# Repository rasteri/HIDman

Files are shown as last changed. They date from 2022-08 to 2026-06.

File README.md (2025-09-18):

# HIDman
## USB HID to XT / AT / PS/2 / Serial converter

HIDman is an open source device to allow the use of modern USB keyboards and mice on legacy PCs.

Peripherals that support legacy PCs are becoming hard to find, especially for the very first PCs. This project aims to provide a simple cheap solution that will cover everything from the original IBM 5150 PC all the way up to modern computers that have PS/2 ports.

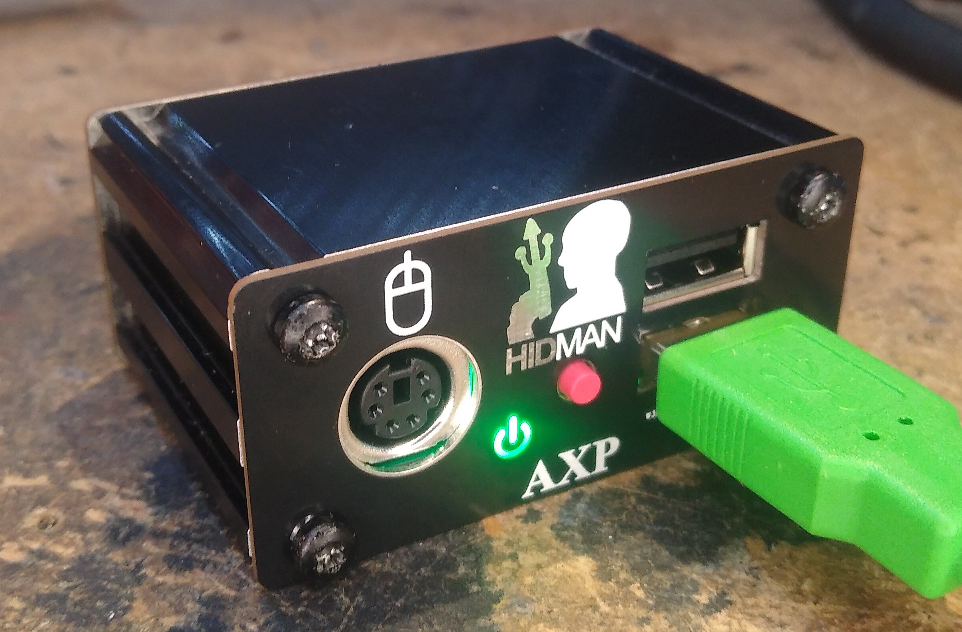
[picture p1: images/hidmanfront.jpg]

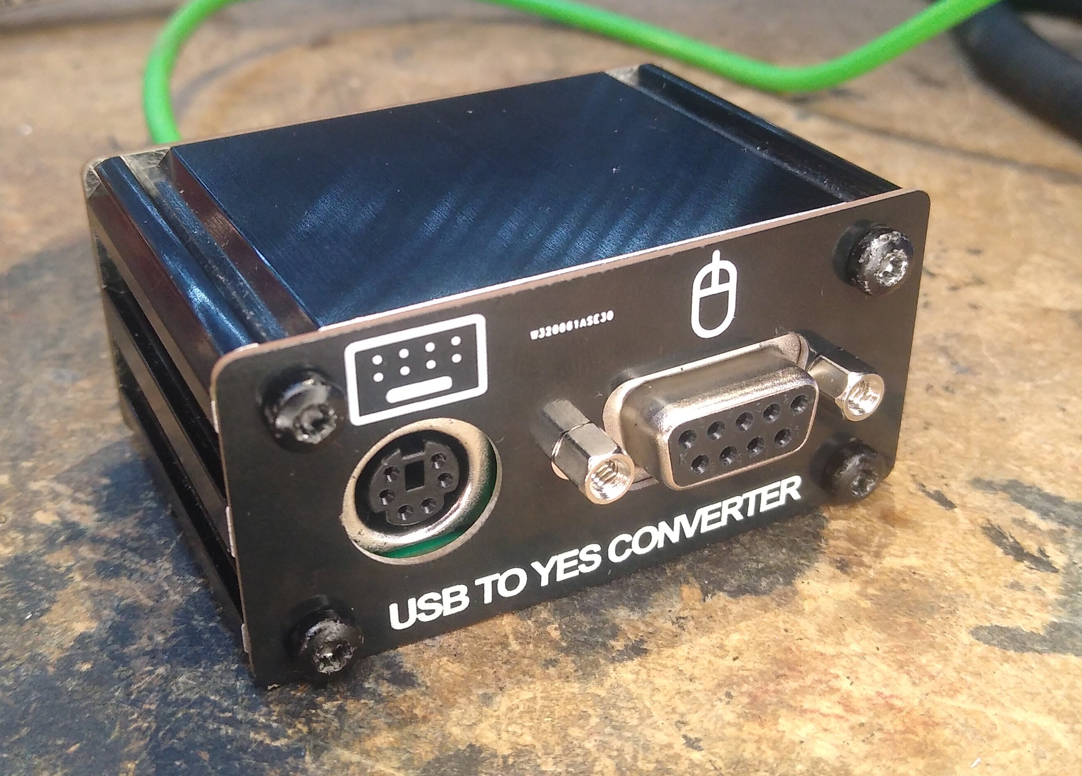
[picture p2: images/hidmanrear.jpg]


# Features

* (should) Support the majority of standard USB keyboards and mice, including ones that use wireless dongles.
* Also supports (some) USB Game controllers - buttons/axes are mapped to keypresses or mouse actions
* Can emulate the following keyboards :
  * Original IBM PC, XT and clones
  * AT / PS/2
  * Amstrad PC (PC1512, PC1640, PC2xxx, PC3xxx, PC4xxx)
* And the following mice :
  * Serial Mouse (with optional Logitech-style 3rd button)
  * PS/2 Mouse (with optional Intellipoint-style scroll wheel and up to 5 buttons)
* Driverless configuration menu - change settings just by opening a text editor

# How to get one

## Purchase : 

* I have some for sale on my tindie page - https://www.tindie.com/products/rasteri/hidman/
* If you're in the US, retro hack shack also has stock - https://retrohackshack.com/product/hidman-usb-keyboard-converter/

## DIY : 

* Grab an assembled PCB from PCBway : https://www.pcbway.com/project/shareproject/HIDman_USB_to_Retro_PC_Adapter_3b4fb5d5.html
* Also grab the front plate : https://www.pcbway.com/project/shareproject/Front_enclosure_plate_for_HIDman_0aec2ae9.html
* And the rear plate : https://www.pcbway.com/project/shareproject/Rear_Enclosure_for_HIDman_c0ff0b8a.html
* And the enclosure : https://lincolnbinns.com/e-case-a-black-40mm.html
* Don't forget 8x screws : https://lincolnbinns.com/e-case-screws.html (I suggest the thread former ones)
* After assembling the unit, you will need to install firmware. See the "Firmware Update" section below.

# Quickstart Guide

## USB Connection

You can connect many different combinations of USB devices to HIDman.

The most obvious being to connect a keyboard to one USB port, and a mouse to the other one :



Or, you could perhaps connect a wireless keyboard+mouse dongle to one port, and a game controller to the other :



Hub support can be hit-and-miss. This is (mostly) not HIDman's fault - many modern hubs don't support low-speed USB devices properly.

## Newer PCs (PS/2) ###

* Connect male-to-male Mini-DIN cables from HIDman’s keyboard and mouse ports to your PC’s PS/2 ports.
* Turn on your PC.
* If necessary, press HIDman's ⏻ power button to select PS/2 mode (light blue).



## Older PCs (AT/XT and Serial)

* Connect a male-to-male Mini-DIN Cable from HIDman's keyboard port into a Mini-DIN to DIN adapter.
* Connect that adapter to your PC's keyboard port.
* Connect a straight-through male-to-female DE-9 cable from HIDman's serial port to your PC's serial port.
* Turn on your PC.
* Press HIDman's ⏻ power button to select AT mode (light blue), or XT mode (orange) for early 80's IBM PCs and clones.



# Configuration

Configuration is provided through a built-in menu system. No software install is required - all interaction is through the keyboard.

Simply open a text editor on your target PC (eg notepad, edit, vi), then hold HIDman's power button for a few seconds. The menu will be typed out into your text editor.

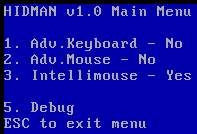
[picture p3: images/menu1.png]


"Adv.Keyboard" and "Adv.Mouse" switch the keyboard and mouse respectively into "Native Mode". This may be required to access certain functions such as scroll wheels and extra buttons on mice.

**Note : Some USB devices with both keyboard and mouse interfaces (e.g. mice with configurable buttons) require both Adv.Keyboard and Adv.Mouse to be enabled otherwise they behave unpredictably.**

"Intellimouse" enables scroll wheel and 5-button support for PS/2 mice.

"Debug" enables the debug menu. The most useful debugging option is "Dump HID Data". Enabling this dumps information about all USB devices connected after that point. 



If you are having trouble getting a USB device to work, enable HID Dumping then connect the troublesome USB device. Wait for it to finish dumping, then press ESC and save the resulting data to a text file. Then send it to me for analysis.

# Firmware Update

Firmware development is continuing, so if you have problems it's always worth updating to the latest version.

If you're on windows, first install WCH's ISP tool - https://www.wch.cn/downloads/WCHISPTool_Setup_exe.html
If on Mac or Linux, install ch55xtool : https://github.com/MarsTechHAN/ch552tool

The next step is to put the HIDman in firmware update mode.

1. Disconnect everything from HIDman, including all USB devices and PCs. (failure to do this may result in damage to HIDman, your PC, or both).
2. Hold down HIDman's ⏻ power button.
3. Use a USB A-to-A cable to connect HIDman's LOWER USB port to a USB port on your modern PC.

If HIDman doesn't appear in your computers' device list, follow the instructions in the "Debricking" section below.

After that, update instructions will depend on your operating system.

## Windows

Follow the instructions in this diagram :



## Linux or Mac

Pass the -f parameter to ch55xtool specify the firmware file to load. For example :

```
python3 ch55xtool.py -f hidman_axp_v1.1.bin
```

## Debricking

If this is your first time programming HIDman, or you accidentally program a corrupted firmware, you can force it into firmware update mode another way. It can be a bit fiddly though.

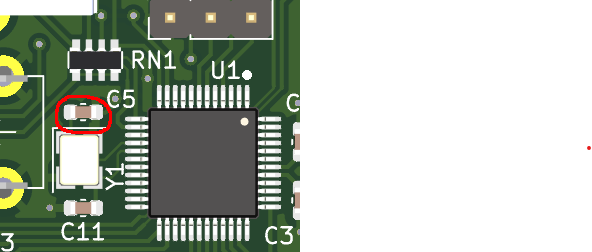
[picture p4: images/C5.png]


1. Disassemble HIDman.
2. Connect the two pads of component C5 (shown above) together using a pair of tweezers or similar.
3. While keeping the pads connected, use a USB A-to-A cable to connect HIDman's LOWER USB port to a USB port on your modern PC.

# Advanced Setups

## Combined PS/2 port
HIDman actually outputs keyboard *and* mouse signals on **BOTH** PS/2 connectors. If you have a PC that can take advantage of this (typically Mini PCs or Laptops), you can keep the cabling neater by using only one cable. **NOTE : You will need to enable "PS2 AUX Output" in the advanced menu.**



Note that there are two different types of Combined PS/2 ports, and HIDman provides for both types. Generally, laptops will need plugged into the Mouse port on HIDman, and Mini PCs want the Keyboard port. If it doesn't work with one port, try the other one.

## Splitter

Another way to take advantage of the Combined PS/2 port functionality is to use a widely-available PS/2 splitter :



This also allows neater cabling, as you could connect both keyboard and mouse ports to the rear, and not have to connect to the front mouse port.

## Technical description

The HIDman is based around the CH559 from WCH, a remarkably flexible chip with **two** USB HOST ports. This makes it ideal for our purposes.

The code is forked from atc1441's excellent repository - https://github.com/atc1441/CH559sdccUSBHost

PCB and enclosure was designed in KiCad - source files are in the hardware directory.

Development is very active but it is usable in its current state.

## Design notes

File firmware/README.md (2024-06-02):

# HIDman
## USB HID to XT / AT / PS/2 / Serial converter

HIDman is an open source device to allow the use of modern USB keyboards and mice on legacy PCs.

Peripherals that support legacy PCs are becoming hard to find, especially for the very first PCs. This project aims to provide a simple cheap solution that will cover everything from the original IBM 5150 PC all the way up to modern computers that have PS/2 ports.

Hidman Front
Hidman Front

## Features

* (should) Support the majority of standard USB keyboards and mice, including ones that use wireless dongles.
* Also supports (some) USB Game controllers - buttons/axes are mapped to keypresses or mouse actions
* Can emulate the following devices :
* * OG IBM PC / XT Keyboard
  * AT / PS/2 Keyboard
  * Serial Mouse (with optional Logitech-style 3rd button)
  * PS/2 Mouse (with optional Intellipoint-style scroll wheel and up to 5 buttons)
* Driverless configuration menu - change settings just by opening a text editor

## Technical description

The HIDman is based around the CH559 from WCH, a remarkably flexible chip with **two** USB HOST ports. This makes it ideal for our purposes.

The code is forked from atc1441's excellent repository - https://github.com/atc1441/CH559sdccUSBHost

PCB and enclosure was designed in KiCad - source files are in the hardware directory.

Development is very active but it is usable in its current state.

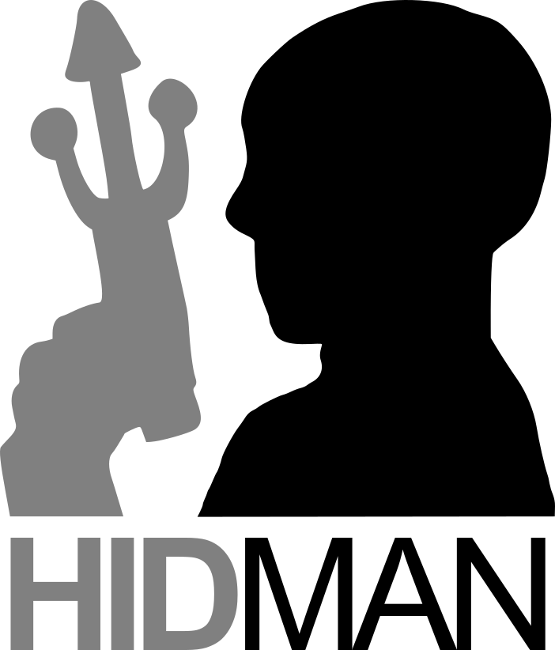
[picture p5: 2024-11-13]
hardware/assets/path676.png

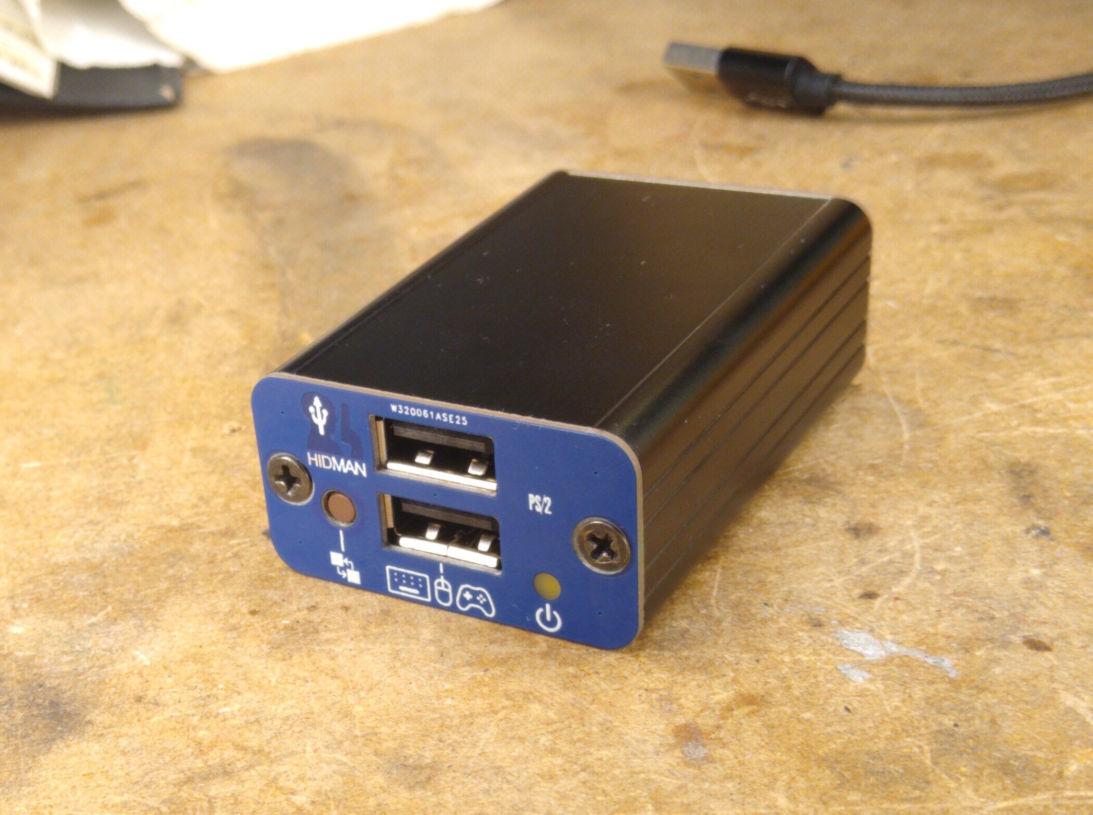
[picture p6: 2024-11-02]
hardware/ps2/images/HIDman-ps2-front.jpg

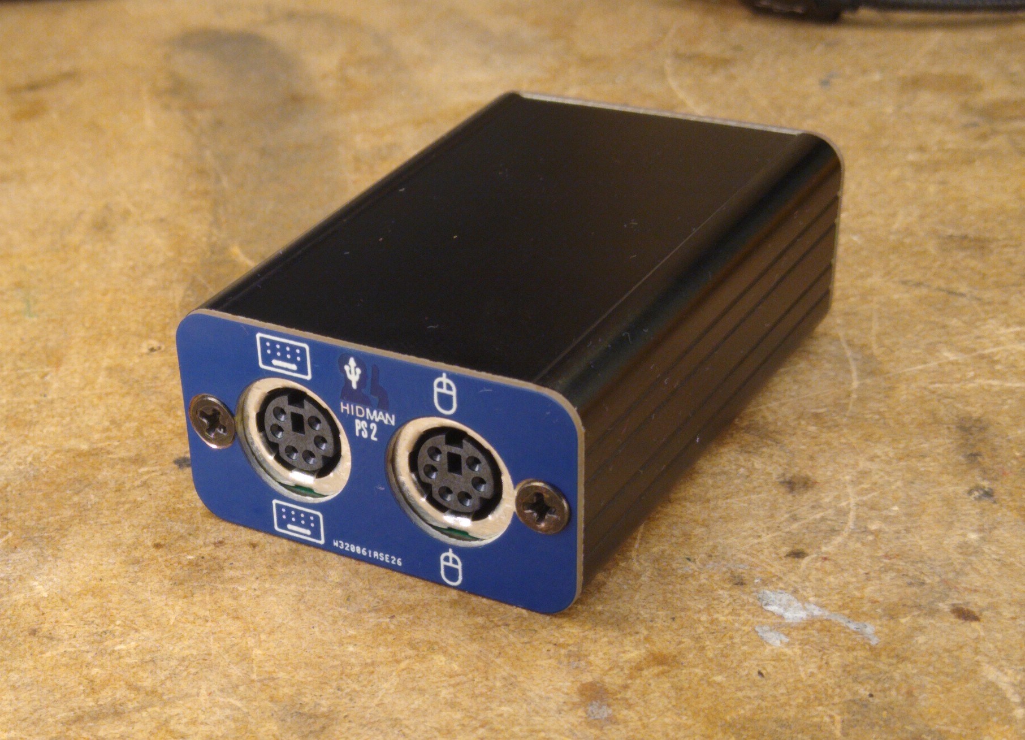
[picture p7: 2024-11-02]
hardware/ps2/images/HIDman-ps2-rear.jpg

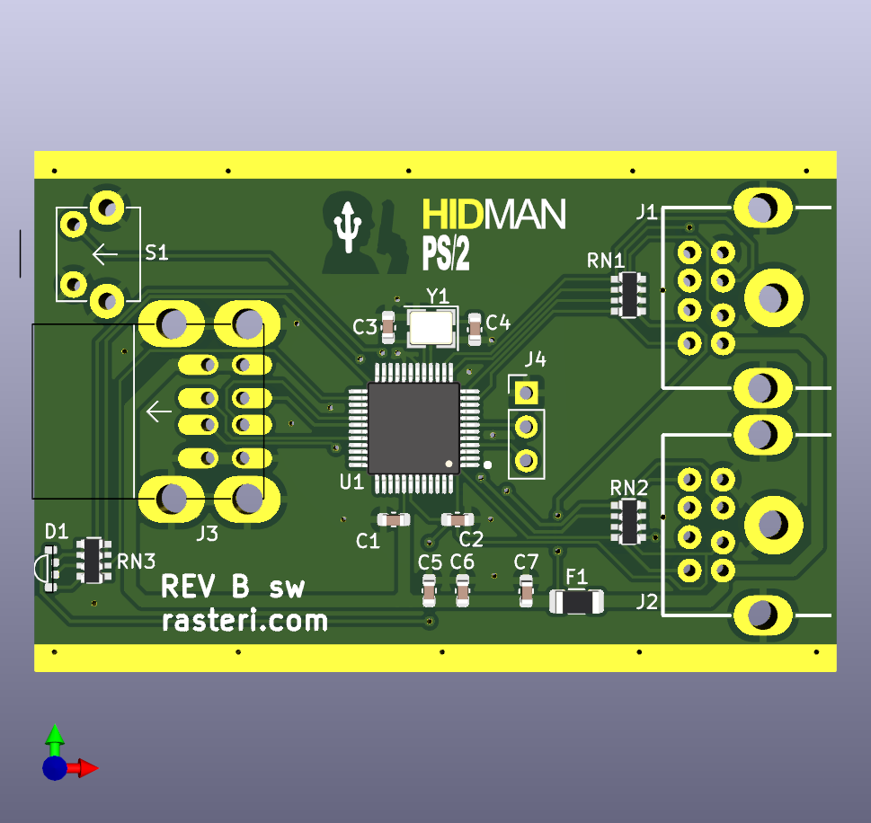
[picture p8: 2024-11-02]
hardware/ps2/ps2usb.png

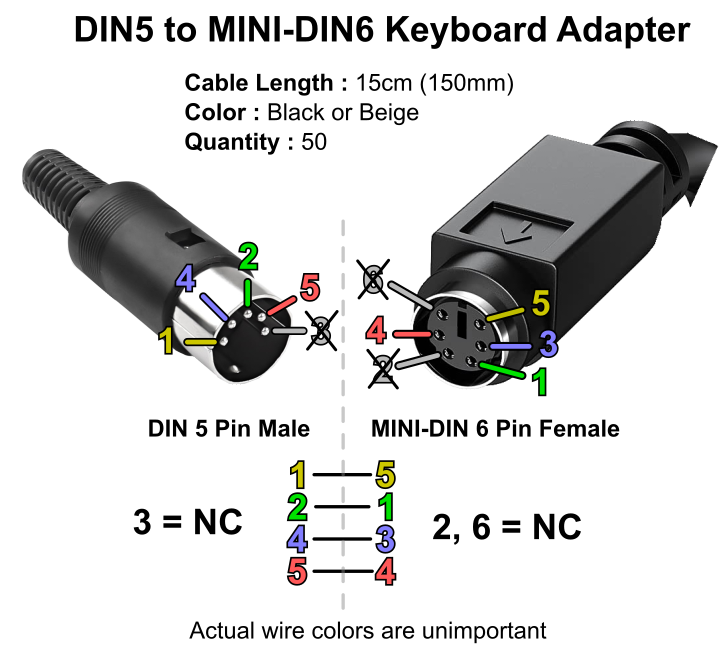
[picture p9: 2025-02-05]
images/adapt.png

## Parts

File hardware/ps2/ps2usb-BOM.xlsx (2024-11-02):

Designator | Manufacturer | Part Number | Description | Footprint | JLCPCB Part #
C1,C2,C5,C6,C7 | Samsung | CL10A335KP8NNNC | Cap, 0603, MLCC, 3.3uF, 10v, X5R | SMD 0603 | C342962
C3,C4 | YAGEO | CC0603JRNPO9BN100 | Cap, 0603, MLCC, 10pF, 50v, C0G | SMD 0603 | C1634
D1 | Harvatek | B3173BGR-20C0001Q3U1930 | LED, RGB, Common Anode | SMD | C2827295
RN1,RN2 | YAGEO | YC164-FR-071KL | Res Array, 4x0603, 1K | SMD 4x0603 | C110021
RN3 | YAGEO | YC164-JR-07120RL | Res Array, 4x0603, 120R | SMD 4x0603 | C136835
J1,J2 | HOOYA | DIN-603 | Conn, Mini-DIN, 6pin | Through-Hole | C7428703
J3 | SHOU HAN | AF SS-JB17.6 | Conn, USB, 2.0, Type-A, Dual | Through-Hole | C456021
J4 | DO NOT POPULATE | DO NOT POPULATE | DO NOT POPULATE | DO NOT POPULATE
U1 | WCH | CH559L | IC, CH559L | SMD QFP48 | C150548
S1 | CUI | TS11-674-80-BK-160-RA-D | Switch, Tactile, Right Angle, 8mm Actuator Length | Through-Hole | C7074168
F1 | BHFUSE | BSMD1206-050-30V | 500mA | SMD 1206 | C883126
Y1 | YXC | X322512MSB4SI | 12MHz | SMD 3225 | C9002

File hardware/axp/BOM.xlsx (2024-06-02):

Item # | Designators | Quantity | Manufacturer | Part no | Desc | Package | Type
1 | C4,C7,C1,C6,C10,C9,C2,C3,C8,C12 | 10 | Samsung | CL10A335KP8NNNC | Cap, 0603, MLCC, 3.3uF, 10v, X5R | SMD 0603 | SMD
2 | C11,C5 | 2 | YAGEO | CC0603JRNPO9BN100 | Cap, 0603, MLCC, 10pF, 50v, C0G | SMD 0603 | SMD
3 | J3,J1 | 2 | HOOYA | DIN-603 | Conn, Mini-DIN, 6pin | Through-Hole | TH
4 | D1 | 1 | TUOZHAN | P4-1204RGBWS2-1.5T-A | LED, RGB, Common Anode | SMD | SMD
5 | RN3 | 1 | YAGEO | YC164-JR-07120RL | Res Array, 4x0603, 120R | SMD 4x0603 | SMD
6 | RN1,RN2 | 2 | YAGEO | YC164-FR-071KL | Res Array, 4x0603, 1K | SMD 4x0603 | SMD
7 | J2 | 1 | SHOU HAN | AF SS-JB17.6 | Conn, USB, 2.0, Type-A, Dual | Through-Hole | TH
8 | U1 | 1 | WCH | CH559L | IC, CH559L | SMD QFP48 | SMD
9 | U2 | 1 | Texas Instruments | MAX232IDR | IC, MAX232 | SMD SOIC16 | SMD
10 | S1 | 1 | Shenzhen Kinghelm Elec | KH-6X6X9H-ZJ | Switch, Tactile, Right Angle, 9mm Actuator Length | Through-Hole | TH
11 | J5 | 1 | DO NOT POPULATE | DO NOT POPULATE | DO NOT POPULATE | DO NOT POPULATE | -
12 | J4 | 1 | XUNPU | D-SUB-DR-9PCM-CB | Conn, D-Sub, DE-9, 9-pin | Through-Hole | TH
13 | F1 | 1 | BHFUSE | BSMD1206-050-30V | 500mA | SMD 1206 | SMD
14 | Y1 | 1 | YXC | X322512MSB4SI | 12MHz | SMD 3225 | SMD

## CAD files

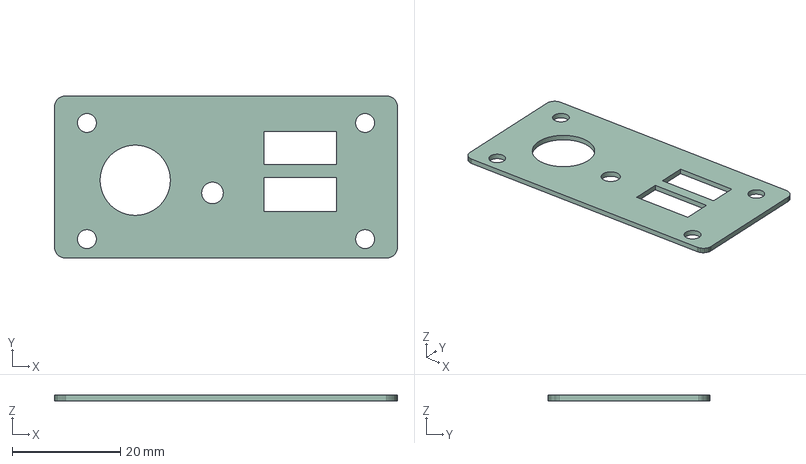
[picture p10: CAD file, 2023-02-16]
hardware/axp/enclosure/frontcase/frontcase.step
63.5 x 30.0 x 1.07 mm

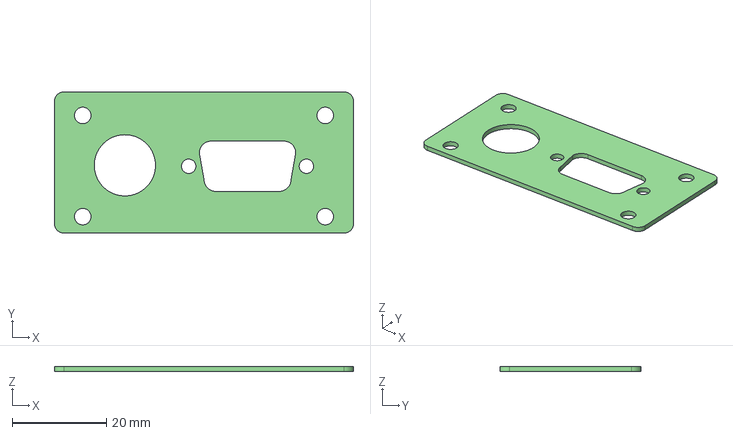
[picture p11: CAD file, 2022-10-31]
hardware/axp/enclosure/rearcase/rearcase/rearcase.step
63.5 x 30.0 x 1.09 mm

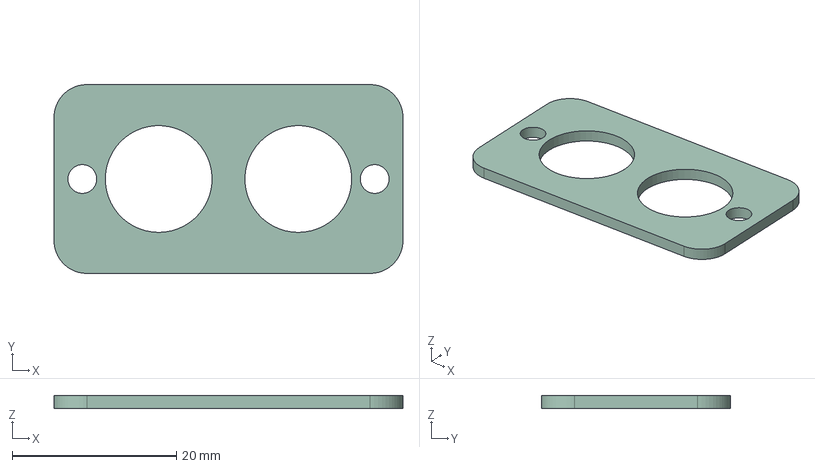
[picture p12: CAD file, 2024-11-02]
hardware/ps2/enclosure/frontcase/frontcase.step
42.5 x 23.0 x 1.60 mm

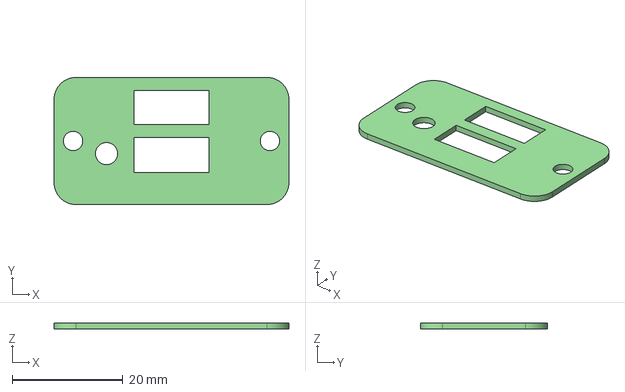
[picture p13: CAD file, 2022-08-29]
hardware/ps2/enclosure/rearcase/rearcase.step
42.5 x 23.0 x 1.09 mm

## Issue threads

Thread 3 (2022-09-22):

Intellimouse features not implemented

rasteri, 2022-09-22:

jarpatus, 2024-05-04:
@rasteri, I am trying to add Intellimouse support and am almost there, but have treoubles on last steps... I wonder if you are willing to help?

I have implemented PS/2 command buffer so I can detect when driver enables intellimouse (also enabled support for PS/2 resolution and scaling on commands, but those are not that important). I have expanded PS/2 related code to support Z-axis and 4-byte reports. At the moment middle click works under DOS and Win98 and wheel scrolling does work if I fake it (e.g. map mouse Y-axis to wheel like I've done for debugging purposes).

However, I am unable to wrap my head around USB code, reports and stuff. I cannot figure out how I can make USB code to support scrolling. If you are willing to help, could you take a look of this commit on my fork:

https://github.com/rasteri/HIDman/commit/f6b9754f5e3a20176eb96b2270da4323d281251c

In ps2protocol.c I think I was able to do what it takes (case MAP_MOUSE_WHEEL), but in parsedescriptor.c my modifications do nothing (case REPORT_USAGE_WHEEL, do not mind swapped Y and wheel, for debugging only). Any hints?

jarpatus, 2024-05-05:
Hacked together wheel support, it works with ctmouse and under Windows98! But it's a hack as I am parsing wheel input from bare data...

rasteri, 2024-05-06:
Hey I'll look at getting it integrated with the HID report stuff. It's a pretty complicated scheme.

jarpatus, 2024-05-06:
@rasteri, I was able to make it work by adding wheel to standard mouse descriptor... not sure if you can do it like this, I still do not understand HID report descriptors and reports well enough...

https://github.com/rasteri/HIDman/commit/96a871553ec7181b16096e851a17616f6e65b321

jarpatus, 2024-05-06:
Thanks! FYI; I felt andventurous and added support for 5 button intellimouse, this is in it's separate branch intelli5b in my fork. Feel free to try it out if you wish. I had to modify standard mouse descriptor even more.

At least under Win9x IntelliPoint 3.0 software will now detect mouse as Intellimouse Explorer with 5 buttons and buttons really do work. I have no modern machines with PS/2 so I could try it out e.g. with Win11 or so...

rasteri, 2024-05-07:
5-button code works flawlessly in Windows 10. I think we can call this one fixed.

Thanks again for your contribution!

Closed 2024-05-07.

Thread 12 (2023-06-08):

Possible to output combined keyboard and mouse?  (re: weeCee PS/2 input)

sofakng, 2023-06-08:
Thanks for the excellent project!

Would you consider adding a feature (to both the 'legacy' PS2 and newer AXP versions) to output both keyboard and mouse on a single PS/2 cable?  For example, your weeCee only has a single PS/2 input and requires both signals on the same cable.

Thanks!

rasteri, 2023-06-08:
I already plan to add this feature - the ports are already wired up for this.

sofakng, 2023-06-08:
Great, thanks so much!  I posted a couple of other questions on Vogons if you have a minute to check.  Thanks again!

rasteri, 2024-05-06:
This is now implemented

Closed 2024-05-06.

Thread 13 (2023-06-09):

What enclosure are you using for the original PS/2 version?

sofakng, 2023-06-09:
What enclosure are you using for the original PS/2 version?

It looks like a Hammond case similar to your weeCee case but I'm not sure.

Thanks for the help!

EDIT:  I think it might be the [Hammond 1455D602BK](https://www.hammfg.com/part/1455D602BK?referer=1203)?

rasteri, 2023-06-09:
It's the 1455D601BK, but the 602 will also work just get whatevers cheaper.

Sorry I'm ignoring vogons, I'm preparing the release of another open source project, Once its done I'll get back to preparing the Hidman 1.0 release

sofakng, 2023-06-09:
No problem and thanks for the reply.  Sorry about the repeated questions.  I was just hoping to order some parts because it takes a few weeks to arrive.

It looks like the only difference between the 601 and 602 are the metal endcaps on the 601 which you aren't using anyways.

Thanks again and I can't wait to see your next project!

Closed 2024-05-07.

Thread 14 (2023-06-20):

Restore PS/2 version functionality

sofakng, 2023-06-20:
Sorry to bother you again...  Can you confirm this is the correct orientation for the LED?  (green dot towards PCB)

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

rasteri, 2023-06-21:
yeah I think that's right.
unfortunately the PS/2 version will need some firmware tweaks to work again - the current code only works for AXP...

I should have some time to work on integrating them soon

sofakng, 2023-06-21:
Ahhh, OK.  That probable explains why I was able to flash the chip but it doesn't seem to work.  I'll keep an eye on any updates.  Thanks!

yarodin, 2023-06-24:
Same story here. Waiting fixed firmware for PS/2 version.

rasteri, 2024-05-07:
This has been fixed - latest firmware supports PS/2 version again.

Closed 2024-05-07.

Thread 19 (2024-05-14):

Some USB Hubs don't work

rasteri, 2024-05-14:
This does not affect all hubs. In fact it doesn't affect all USB devices on failing hubs.

Common thread with failing hubs seems to be that low-speed devices fail whereas high-speed devices work.

Note this fault doesn't seem to even be specific to particular hub controllers - I have two HS8836A-based hubs that appear to have identical components (though different board layouts) - one works and one doesn't.

Also interestingly certain STM32s have problems with low-speed devices on hubs, there is a silicon errata to that effect. I wonder if the problem is similar on the CH559

rasteri, 2024-05-14:
So I did some more testing, the USB hubs that don't work ALSO don't work on other USB1.1 hosts (namely old PCs).

USB 1.1 full speed devices do not exhibit this problem, nor do USB2.0 hosts.

This is the chain of devices required to make them fail :

USB1.1 low speed device ---> USB 2.0 hub --->USB1.1 Host (i.e. hidman or PC)

I'm beginning to suspect that there is a general problem with many USB2.0 hubs where they don't work correctly with USB1.1 low speed devices on USB1.1 Hosts. This may not be fixable.

rasteri, 2024-05-25:
Remaining hub problems have been solved by a combination of :

1. Giving up (certain hubs just don't like low speed devices on USB1.1 hosts, nothing we can do about that)
2. Adding a 12MHz crystal to the board (certain hubs are picky about timing)

Closed 2024-05-25.

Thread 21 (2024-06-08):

Latency is unknown

rasteri, 2024-06-08:
latency should be pretty low but it would be nice to get exact figures.

Probably best way to measure this is just by looking at the USB and PS/2 lines on a logic analyzer

rasteri, 2025-03-06:
I've done some rough preliminary latency measurements.

Latency is a pretty consistent **1ms** [when measured the way USB4VC does it (USB packet start -> PS/2 Packet Start). ](https://github.com/dekuNukem/USB4VC/blob/master/technical_notes.md#latency-information). This is equivalent to USB4VC when run on a Raspberry Pi 2 (also 1ms), and double USB4VC on a Pi4 (0.5ms).

To put things in perspective though, I also measured it a different way - I wrote a small DOS program to emit a beep whenever a key is pressed. Then with a microphone recorded the audio of me pressing a key. The average time between keypress and beep was 25ms on both the USB keyboards I tried. We can surmise that USB4VC would manage 24.5ms in this test.

Then I tested a random PS/2 keyboard I had (an HP OEM thing) and it came out around 20ms. My program only adds around 0.2ms of this latency (I measured with a logic analyzer).

So given we're talking about double-digit inherent latencies anyway, I don't think it's worth chasing fractions of a millisecond on top of that - but I've done almost zero optimization at this point so I'm sure we could get closer to USB4VC if we really wanted to.

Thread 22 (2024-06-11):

Centron does not match Gerbers?

foenixrising, 2024-06-11:
Giving this a shot and sent files into PCBway for fabrication.  Feedback was that components do not align.  Have Gerbers changed but new Centron file hasn't been pushed yet?  Help appreciated, Michael

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

rasteri, 2024-06-11:
That centroid file is for the AXP version, not the PS/2 version.

The PS/2 version is missing some features (crystal), I recommend going with the AXP version.

And even then I'd wait till I do an official release. Will be in a couple of weeks hopefully.

foenixrising, 2024-06-11:
Ah, my bad then.  Does the PS/2 version work as of the rev a. board?  (sorry for the bother) if so, I'll send them the updated file, I'm already $100 in on this.  A friend passed me the repo link and I mistakenly took the comments of it being stable but active on face value.  Thanks again.

rasteri, 2024-06-11:
The PS/2 version works somewhat but not on all devices (it has trouble with some hubs).

Did you send them the BOM from the AXP version too? If so they've already priced up the extra AXP components so the AXP won't cost any more.

I would just tell them to make an AXP version instead of the PS/2. Actually works out cheaper (unless you've already bought the enclosure)

foenixrising, 2024-06-11:
I must have sent them a mismatch of Gerber (I'm guessing PS/2) and the BOM and centroid from the AXP.  Can you confirm for me?  You are obviously in the middle of it and I'm lost : )

Also, my needs are simple; using a modern keyboard with no hub and no other USB devices along the bus and want PS/2 keyboard output.  Another use case is a somewhat modern arcade spinner and I'll want PS/2 mouse output.  Alsoalso, I have no idea what AXP stands for?

I don't mean to take up all of your time, if you just tell me which files to use, I'll get the build done and it will either work or not.  I can resubmit in a month or whatever but if this can be made to work, even in the first corner case above, I'll be satisfied.  Thx again.

[Centroid (1).csv](https://github.com/user-attachments/files/15789666/Centroid.1.csv)
[BOM (5).xlsx](https://github.com/user-attachments/files/15789667/BOM.5.xlsx)
[gerbers (1).zip](https://github.com/user-attachments/files/15789668/gerbers.1.zip)

rasteri, 2024-06-11:
Yes, that's the PS/2 version's gerbers with the AXP version's BOM and Centroid.

I consider the PS/2 version to be the "old" version. I never made a BOM or centroid for it as I only ever hand-assembled it.

AXP stands for **A**T/**X**T/**P**S2, it does everything the PS/2 version does and it also has a serial port. It even costs less than the PS/2 version because the enclosure is much cheaper.

Unless it's too late, I would recommend telling PCBWay to build you an AXP version instead. These are the gerbers : https://github.com/rasteri/HIDman/raw/main/hardware/axp/gerbers/gerbers.zip

If you have to have the PS/2 version then I may be able to generate a BOM and centroid

foenixrising, 2024-06-11:
If you've moved on and are only working on the AXP, I'll just send them the new gerber zip and have them remake the board.  The other boards can be used as keychains or something.  Thanks for the feedback, I'll bug you in about a month once they arrive to see where the code is at.  They don't have the PS/2 connectors there so I ordered a bunch from Amazon.  Otherwise, I'm in good shape now, thank you for the help.

Closed 2024-06-11.

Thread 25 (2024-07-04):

Some devices don't like to be hotplugged/re-enumerated

rasteri, 2024-07-04:

rasteri, 2024-07-28:
this was fixed in usbrefactor branch (now merged)

Closed 2024-07-28.

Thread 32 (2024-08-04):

Problem with cursor keys and some special keys

foenixrising, 2024-08-04:
Thx. for that .hex; flash worked, the module mostly works except for two of what appear to be software/firmware issues:
1. cursor keys, home, insert, etc. do not send any codes to the host; other keys work = all printable, escape (27), return (13), control keys are all normal.  Have tried an old iMAC keyboard that works on a PC and with a newer WASD keyboard that works on a PC or my Macbook
2. the built in menu sends garbage, or at least, some unprintable chars.  Here are the ASCII values of what is sent:

101, 99, 57, 205, 162, 251, 161, 212, 162, 190, 8, 197, 52, 13, 195, 13

If I blindly type "1", I get additional garbage chars.  Any guesses?

rasteri, 2024-08-05:
What type of PC are you connected to?

rasteri, 2024-08-05:
Oh and have you tried doing a HARD factory reset from the menu? (or alternatively check "clear dataflash" when you program the firmware)

rasteri, 2024-08-05:
Yeah there's an option in the menu for "81-key keyboard" that disables a lot of keys. It's intended for REALLY old PCs but if you didnt clear the dataflash it might have defaulted to on. My guess is thats why half the keys don't work.

To be honest I've had problems with the menu corrupting on other non-PC devices, I'm investigating as we speak.

rasteri, 2024-08-05:
Most PS/2 computers will use the Inhibit feature of PS/2 to tell HIDman to delay sending text if it can't process it quickly enough.

foenixrising, 2024-08-05:
I’ll ask the person that did the Verilog if that block included it.  Probably did… just a hunch I had… looks a lot like serial data that is corrupt.  It prints some… garbage then pauses, the I can type a key and the incorrect char echos the more garbage.  I’m unable to ESCape out of that command mode at that ping.  Just wondered if a brief delay between chars would make a diff but I’m not asking for that… will see if I can get anywhere later tonight when I’m home.

Get Outlook for iOS<https://aka.ms/o0ukef>
________________________________
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

rasteri, 2024-08-05:
If you increase PS2_RATE_LIMIT to a few thousand in ps2.h then that will slow everything down. I have to do this on XT PCs.

https://github.com/rasteri/HIDman/blob/7ea815a1be558316a716997f10e8d90ab4194970/firmware/ps2.h#L11

However this may not make a difference. I have other PS/2 hosts that corrupt in a similar way to yours and limiting the rate makes no difference. My guess is it's an incompatibility caused by the inhibit logic but I don't know if it's HIDman's fault or the host's fault.

foenixrising, 2024-08-05:
Any chance you can build one for me with a horse at a delay?  For whatever reason my attempt to build a compilation env and run Make fails.

Get Outlook for iOS<https://aka.ms/o0ukef>
________________________________
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

foenixrising, 2024-08-05:
Well, good news/same news.  Good news is clearing out dataflash did the trick; cursor keys and other keys all work now.  'same' news is chars received are still garbled, but are partially discernable now.  Of course typing rate is very slow and I had high hopes but still nothing wonderful; I'll email you a pic of the output.

So two quick questions; outside of the config not working, is there anything else that might not work properly (as mentioned all keys now work).  Second question, how does one use the 9-pin serial Mouse?  I tried plugging in a USB Mouse on one side and monitored the serial port on the other but didn't see any output?  Thanks.  I have 10 of these built, do you want me to mail you two (not sure how far your hardware design has evolved but if you've only built one or two by hand, I can give you a pair).  Let me know and thanks.

foenixrising, 2024-08-05:
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

This is just a simple basic program the does "inkey()" and prints the char with ASCII # and then cprints (which essentially prints the graphic characters to the screen, as you can see with the 13).  Interestingly, all of these chars are normal ascii range values as opposed to the first time I tried it with the 1.1 firmware which output high order ASCII 251, etc.  At this point, I'll see if I can get some info from the person that integrated the PS/2, but if you can respond to my prior message, I'll be all set for now.  Thanks again.

rasteri, 2024-08-06:
The serial mouse should just work, no prep necessary. Does the LED on the front of HIDman blink when you move the mouse/press mouse buttons?

The only other bug I'm aware of is the aforementioned issue with certain other non-PC devices. I have some PS/2-to-USB adapters (i.e. the opposite of HIDman) that don't work, and I'm still to figure out what's going on there. I'll make an effort to investigate this week - maybe if I get them to work it will fix your problem too.

Obviously I've mostly been testing with "Normal" PCs so maybe there's a subtle bug in the firmware that PC's dont mind but other devices have problems with. The logic around inhibits is pretty complicated so it's quite possible.

I actually have 20 HIDmen already made up, so no I don't need any more :) I'll probably be selling a few but not until I do some more testing.

foenixrising, 2024-08-08:
Hey again.  Yes then light flashes w mouse movement.  Trying to scope it through a opto just for fun. Do you know what baud rate and data bits etc for a serial mouse or does it depend on the devices?  Thanks.

Get Outlook for iOS<https://aka.ms/o0ukef>
________________________________
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

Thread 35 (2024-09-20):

self-test byte not sent for XT protocol

rasteri, 2024-09-20:
XTs require a self-test byte (0xAA) to be sent after poweron. It's not critical but it causes the 5150/XT BIOS to display a "301" error.

rasteri, 2025-01-18:
User reports that on some 5160 BIOSes, this self-test byte *is* actually neccesary. This issue should therefore be prioritized for the next release

https://minuszerodegrees.net/HIDman%20AXP/HIDman%20AXP.htm

rasteri, 2025-02-05:
fixed as of v1.1.5f

https://github.com/rasteri/HIDman/releases/tag/v1.1.5f

Closed 2025-02-05.

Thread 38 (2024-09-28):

Suggestion: Document PCB ordering process

Sebazzz, 2024-09-28:
I can read circuit diagrams, I can solder, but I've never ordered a custom PCB before. Suggestion to document what options to choose at the PCB vendor (e.g. PCBway) and how to export the Kicad files in a format PCBWay reads. Thanks!

rasteri, 2024-09-29:
I'm working on it. update soon

Sebazzz, 2024-10-05:
Thanks!

rasteri, 2024-11-07:
OK my video about HIDman includes info on how to order everything : https://youtu.be/44tg6oXGmYI?t=614

Closed 2024-11-07.

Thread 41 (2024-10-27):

Firmware compile error

klyde2278, 2024-10-27:
Hi! I wanted to compile the firmware with BOARD_TYPE = BOARD_MINI, OSC_TYPE = OSC_INTERNAL, and BOARD_OPTIONS = OPT_DEFAULT options activated in the Makefile, under Linux Mint, SDCC 4.0.0, make 4.3-4.1

I never compiled a firmware before. It crashes with the following error.
Do you know what can cause this? Thank you very much for your help. Cheers! Klyde.
```
sdcc -c -V -mmcs51 --model-large --stack-auto --xram-size 0x1600 --xram-loc 0x0200 --code-size 0xEFFF -I/ -DFREQ_SYS=48000000 -DBOARD_MINI -DOPT_DEFAULT -DOSC_INTERNAL  -o build/andyalloc.rel andyalloc.c
+ /usr/bin/sdcpp -nostdinc -Wall -std=c11 -I/ -DFREQ_SYS=48000000 -DBOARD_MINI -DOPT_DEFAULT -DOSC_INTERNAL -obj-ext=.rel -D__SDCC_STACK_AUTO -D__SDCC_CHAR_UNSIGNED -D__SDCC_MODEL_LARGE -D__SDCC_INT_LONG_REENT -D__SDCC_FLOAT_REENT -D__SDCC=4_0_0 -D__SDCC_VERSION_MAJOR=4 -D__SDCC_VERSION_MINOR=0 -D__SDCC_VERSION_PATCH=0 -DSDCC=400 -D__SDCC_REVISION=11528 -D__SDCC_mcs51 -D__STDC_NO_COMPLEX__=1 -D__STDC_NO_THREADS__=1 -D__STDC_NO_ATOMICS__=1 -D__STDC_NO_VLA__=1 -D__STDC_ISO_10646__=201409L -D__STDC_UTF_16__=1 -D__STDC_UTF_32__=1 -isystem /usr/bin/../share/sdcc/include/mcs51 -isystem /usr/share/sdcc/include/mcs51 -isystem /usr/bin/../share/sdcc/include -isystem /usr/share/sdcc/include  andyalloc.c
andyalloc.c:56: error 78: incompatible types
from type 'unsigned-char near* auto'
  to type 'unsigned-char auto'
make: *** [Makefile:75 : build/andyalloc.rel] Error 1
```

rasteri, 2024-10-28:
I'm on SDCC 4.4, try that instead.

Also do a pull before building, I've just merged the hidman-mini and micro code.

klyde2278, 2024-10-28:
Hi! Thank you SDCC 4.4.0 did the trick for the previous source version (1.1.3) and I was able to build a HIDman.bin and HIDman.hex files.

But since you merged serisman PR, I wanted to build again (with the same Makefile options as previously) and now I came across the following error (sorry for being a pain):

+ /usr/local/bin/sdcpp -nostdinc -Wall -std=c11 -I/ -DFREQ_SYS=48000000 -DBOARD_MINI -DOPT_DEFAULT -DOSC_INTERNAL --obj-ext=.rel -D__SDCC_STACK_AUTO -D__SDCC_CHAR_UNSIGNED -D__SDCC_MODEL_LARGE -D__SDCC_INT_LONG_REENT -D__SDCC_FLOAT_REENT -D__SDCCCALL=0 -D__SDCC=4_4_4 -D__SDCC_VERSION_MAJOR=4 -D__SDCC_VERSION_MINOR=4 -D__SDCC_VERSION_PATCH=4 -DSDCC=444 -D__SDCC_REVISION=15057 -D__SDCC_mcs51 -D__STDC_NO_COMPLEX__=1 -D__STDC_NO_THREADS__=1 -D__STDC_NO_ATOMICS__=1 -D__STDC_NO_VLA__=1 -D__STDC_ISO_10646__=201409L -D__SIZEOF_FLOAT__=4 -D__SIZEOF_DOUBLE__=4 -D__SDCC_BITINT_MAXWIDTH=64 -isystem /usr/local/bin/../share/sdcc/include/mcs51 -isystem /usr/local/share/sdcc/include/mcs51 -isystem /usr/local/bin/../share/sdcc/include -isystem /usr/local/share/sdcc/include  -xc linkedlist.c
linkedlist.c:63: warning 283: function declarator with no prototype
linkedlist.c:67: warning 84: 'auto' variable 'list' may be used before initialization
+ /usr/local/bin/sdas8051 -plosgffw build/linkedlist.rel build/linkedlist.asm
make: ***  No rule to build target « build/scancode.rel », needed for « build/hidman.ihx ». Stop.

rasteri, 2024-10-28:
ah I think that's because scancode.c was stored as all-caps (damn Turbo C...). try again now

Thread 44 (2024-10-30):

PS/2 and mouse incompatibilities

pdaderko, 2024-10-30:
I recently built a couple HIDman AXP (Rev C) boards and loaded them with FW v1.1.3, and I've encountered some PS/2 and mouse functionality/incompatibility issues.  I'm hoping you can either help me resolve them, or tell me how I can best help improve HIDman.

First, I have no PS/2 mouse functionality at all when using a cheap PS/2 to USB adapter or connected to an older HP EliteBook 6930p docking station.  Both of those work with a true PS/2 mouse.  The USB adapter is pictured at the bottom... I don't remember where I got it, but it shows up as VID: 0x13BA PID: 0x0018.  Keyboard functionality seems to work on both of those.  I have the mouse PS/2 cable plugged into the side w/ the USB connectors, and KB PS/2 cable plugged into the side w/ the RS232 connector, which I think is correct.

I have a KVM cable with a built-in PS/2 to USB adapter (VID: 0x0557 PID: 0x2221), which does work with HIDman, so I'm pretty sure my HIDman builds are working correctly, and is compatible with the USB mouse I was using.  I've got a few other systems with PS/2 ports that I'll be testing with shortly.

I also have a wireless keyboard and mouse combo (also pictured at the bottom): https://www.amazon.com/gp/product/B078G77FK8/ (Miritz 2.4GHz Wireless Mini Keyboard with Mouse Touchpad) that seems to have a working keyboard, but the mouse has weird behavior.  Left/right on the mouse moves the cursor up/down, and if I hold a mouse button, any mouse movement will also move to the right.  If I change the mouse settings to "Advanced USB - Yes", then it seems to function correctly, though has very choppy movement.  It isn't choppy when natively connected to a PC, and a regular USB mouse isn't choppy through HIDman with the same settings.

And while the keyboard seems to generally work, I've had quite a few issues with the menu, which seems like it'd be PS/2 keyboard related.  I have never gotten the menu to work with the "good" PS/2 to USB adapter (0x0557/0x2221) - I usually get something like below, which looks like it's trying, but has a bunch of dropped characters:
```
Ha.
.e2 Mo3  d
mu
```

With the "bad" adapter (0x13BA/0x0018) I usually get just a partial menu (sometimes ending with a bunch of repeated characters), though occasionally get a full menu.  Something like below is pretty typical:
```
HIgame

4. Adv.

ESC to exit menu

Gooddddddddddddddddd
```

I'm happy to dig into these issues - I've got a logic analyzer, oscilloscope, Cynthion (USB analyzer), etc... and plenty of other devices to compare with.  Just looking to help in the most efficient way - if these are known issues that you're working on, I'll just wait... or if log dumps will tell you everything, I can send those your way.  Or if I should start probing lines and looking at timing, voltage levels, etc... I can do that too.

And a couple quick notes on the build - overall, it went smoothly, but I noticed the gerbers posted don't have a solder paste mask layer, and are slightly out of date vs. the latest KiCAD files.  I was able to revert the KiCAD PCB file to the commit matching the gerbers and export it, but having everything matched may make the build easier for others.  And a note about shorting C5 for the initial firmware load on factory fresh CH559L chips (found that on a forum post) would have also saved a few minutes.

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

Thanks

rasteri, 2024-10-30:
All PS/2 to USB adapters that I've tried are pretty buggy.

For a start they don't send the necessary command to enable PS/2 mice. In an older revision of hidman we used to ignore that anyway, but that caused problems with certain BIOSes on real PCs, so the decision was made to support them rather than the PS/2 adapters. Perhaps we could make it an option in the menu.

Regarding the menu issues, if you check with a logic analyzer you'll see that HIDman is sending the correct codes but the adapter is missing half of them. I'd like to get HIDman working with them but even inserting a huge delay between each code doesn't help. I'd ideally like to get these adapters working but obviously they're not really a high priority.

Your PS/2 keyboard/touchpad combo should work though - if you could send me a HID dump that would be great - make sure to move the mouse after it dumps the descriptors, and try it in both advanced and normal USB mode. In fact if you could install USBtreeview and get me all the information there too that would be great :

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

Good shout on the paste layer - PCBway didn't complain so I guess they generated one themselves, but if you fancy posting the paste layer you generated you'd save me some time.

pdaderko, 2024-10-31:
Here's the log in regular mode:
[HID_log.txt](https://github.com/user-attachments/files/17580921/HID_log.txt)

Here's the log in advanced mode:
[HID_log_adv.txt](https://github.com/user-attachments/files/17580923/HID_log_adv.txt)

For both of these, I was moving my finger around in a figure-eight pattern.  Then at the end I alternated clicking the two mouse buttons a bunch of times.

Some good news is that I can confirm HIDman works with my modern motherboard (MSI PRO Z690-A WIFI).

rasteri, 2024-10-31:
Hi, the usbtreeview stuff is great, but those HIDman logs don't include the report descriptors - if you could make sure you unplug/replug your wireless dongle into hidman while the HID is logging that would be great, as it only dumps the report descriptors when you plug something in.

pdaderko, 2024-11-01:
I was wondering about that... you mentioned descriptors, but I didn't see them.

Here they are - regular mode:
[HID_log.txt](https://github.com/user-attachments/files/17595429/HID_log.txt)

Advanced mode:
[HID_log_adv.txt](https://github.com/user-attachments/files/17595430/HID_log_adv.txt)

And I did some quick testing/debugging with the scope last night - the 0x13BA/0x0018 USB adapter looks to hold the clock low to throttle the data until its buffer is clear, so it makes sense that it usually gets long bursts of legible data, and sometimes full menus.  The other USB adapter (0x0557/0x2221) looks like it doesn't do anything to the clock, so HIDman writes at full speed, causing it to drop most of the characters.  Though when powered up the 0x0557/0x2221 adapter looks to enable the mouse, while the 0x13BA/0x0018 adapter doesn't (causing the dead mouse on that one).  If I "initialize" the HIDman mouse with 0x0557/0x2221, then swap the mouse plug to 0x13BA/0x0018, it works.  So yeah, if you could add an option to force enable the mouse, I think that'd be helpful.

I also tried this on my HP 16702B Logic Analyzer, and it doesn't seem to work at all.  But that's not totally surprising, since I've tried 5 or 6 PS/2 devices on it, and only one has actually worked (IIRC an HP PS/2 rack mounted console).  So I'll try to figure out what the difference between the good/bad is.

pdaderko, 2024-11-02:
I built a PS/2 passthrough so I could easily probe the lines to see what the 16702B was doing.  And it looks like the problem is that they don't (always?) follow the PS/2 protocol of pulling the clock low before data low to request a host to device transfer.

During boot, on both the keyboard and the mouse, there's a point where the data line goes low and stays low forever (presumably waiting for a response):
Keyboard:
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
Mouse:
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
pdaderko, 2024-11-02:
I just tried that firmware, and I don't notice any difference (cursor still goes up/down when I move my finger left/right).  I'm no expert on HID stuff, but is it possible that this doesn't support boot mode (and is there an easy way I could check)?

From a quick search, I came across this reddit thread: https://old.reddit.com/r/osdev/comments/unhe5x/about_usb_hid_keyboards/ ... not sure if that applies here.

>BTW, to make the USB HID implementation simple you should use Boot protocol mode. Otherwise you would have to implement a quite involved parser. DON'T assume that all keyboards always use the same packet format in Boot mode and Report mode. DO check that the interface is capable of Boot mode, and ignore it otherwise. DO send the Set Protocol request with the Boot value to the keyboard to initialise the keyboard to Boot mode. When your OS starts talking to it, the mode could be either Report or Boot mode, so just don't assume one or the other.
>
>BTW 2, DON'T assume that the first interface is the keyboard interface. (I've seen that error in host implementations)

rasteri, 2024-11-02:
It CLAIMS to support Boot mode (bInterfaceSubClass is 0x01) but the packets it's giving out aren't in boot mode format.

I already do everything in that reddit post.

I've been meaning to get one of those tiny keyboards anyway so I ordered a very similar unit to yours, hopefully it behaves in the same way.

rasteri, 2024-11-04:
I got one of those tiny keyboards and it fails in the exact same way. Interesting

pdaderko, 2024-11-05:
Great!  Er, well at least it's reproducible and not something weird on my end.  Though let me know if there's anything I can do to help (as I mentioned, I do have a Cynthion, so I can log all the USB traffic if that's helpful).

rasteri, 2024-11-05:
So yeah as we thought it isn't going into boot mode properly. It claims to be but the reports it's sending aren't in boot mode format. So I guess it'll have to run in advanced USB mode.

I've made some changes, does this get it working in Advanced mode for you?
[hidman_v1.1.4beta3.zip](https://github.com/user-attachments/files/17636952/hidman_v1.1.4beta3.zip)

pdaderko, 2024-11-06:
That seems to work the same as before.  As I noted in my original post, if I have mouse set to "Advanced USB - Yes" then it works, though the movement is noticeably choppy.  With "Advanced USB - No" it only moves vertically.

It sounds like you're suggesting this only supports Advanced mode, in which case, do you see the same choppiness, and is that expected for advanced mode?

rasteri, 2024-11-06:
Is there any way you could get me a video of the choppiness

pdaderko, 2024-11-08:
The best way I can describe it is the Wireless KB/Mouse through HIDman in Advanced Mode feels like I'm connected to my computer through a VNC connection, while the wired mouse doesn't feel any different than plugged straight into the host.

I tried a video, but it's hard to capture the choppiness/lag.  So instead I tried coming up with a way to objectively measure it.  In the console of Firefox (Ctrl+Shift+K), I ran:
`onmousemove = function(e){console.log(Date.now(),e.clientX, e.clientY)}`

This logs the current time in milliseconds, as well as the X and Y coordinate of the mouse cursor on every move.  So I did figure-eights with the cursor and plotted the X and Y, as well as measured the average time delta between points.  The cursor was updated on average every ~17ms (60 Hz) for every case except the Wireless KB/Mouse in Advanced Mode, which updated on average every ~40ms (25 Hz).  This only captured the choppiness, though it also feels a bit laggy (but that's harder to definitively measure).

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

From those plots, you can see that the curves are much less smooth on the Wireless KB/Mouse in Advanced Mode, and also the "sensitivity" is noticeably reduced (a figure-eight only goes 200-300 pixels rather than 500-600 when natively plugged in).  Maybe it's throwing away over half of the reported X/Y delta values?

I also ran it in boot mode, which obviously doesn't work correctly, but feels smooth.  I held the button so it'd drift right while moving, and corresponding to the feel, I confirmed that it updated at 60 Hz.

Anyway, I'm not sure if that's helpful, but I appreciate you looking into it! (and the other things I mentioned)

rasteri, 2025-02-05:
latest revision has some optimizations that make mouse smoother in advanced mode. Interested to hear if that improves things.

https://github.com/rasteri/HIDman/releases/tag/v1.1.5f

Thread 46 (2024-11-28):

readme.md - Updated download WCHISP URL

huwbaldwin, 2024-11-28:
The current download link provided gives a 404 error.
The correct link is:
https://www.wch.cn/downloads/WCHISPTool_Setup_exe.html

Cheers,

Closed 2025-03-06.

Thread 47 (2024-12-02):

[Feature Request] Create Mac version with support for ADB and the original Mac 128, 512, Plus keyboard/mouse emulation

aaronnewcomb, 2024-12-02:
Since I mentioned it to Andy, I thought I would open an official issue for tracking this idea. If there were a version of this project that supported ADB and the original Mac formats, it would cover nearly all Macs from the original Mac 128K until the G3 iMac which got rid of the ADB port in favor of USB.

In fact, the form factor of the device could be the same so you could use the same case with a modified faceplate. You would just need to replace one of the PS/2 ports with a 4-pin mini DIN jack and replace the other PS/2 port with an RJ-11 4p4c jack. The 9-pin D-Sub could remain for the old Mac mouse emulation.

There are a number of existing projects that achieve parts of this with dev boards.
adb-usb by gblargg https://github.com/gblargg/adb-usb
ps22plus by n055 https://github.com/n055/ps22plus

rasteri, 2025-01-30:
I think I've tracked down an ADB mac so this may get implemented soon!

rasteri, 2025-01-30:
I still need to find a mac with RJ11 though.

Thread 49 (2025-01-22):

Unusual key repeat

tortion, 2025-01-22:
Experiencing intermittent key repeat between a MyRetro 64 USB keyboard (with Cherry MX switches) and a Foenix F256K using PS/2.  The HIDman converts from USB to PS/2 in this case.

Certainly, key repeat is supported such that after a short delay, held keys will repeat characters but in this case, it feels like the HIDman is repeating certain chars upon first press, either two or more chars within a split second.

I will try to reproduce this on another machine but wanted to simply ask if there have been any issues such as this on a prior firmware?  If not, feel free to simply close this; if so, let me know if there is anything I should try; I'll be back to check up on your commends and thank you!

rasteri, 2025-02-03:
It seems that quite a few non-PC PS/2 devices don't work very well. I'm seeing similar issues with some of my hardware.

It's possible I need to tweak the timings slightly.

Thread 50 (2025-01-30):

Scancode set 3 support?

techomancer, 2025-01-30:
Hi,
SGI machines require PS/2 scancode set 3 support. So HIDMan doesn't work on them,

rasteri, 2025-01-30:
Oh interesting, I've tried HIDman on some SGI machines and it seemed to work but I guess they're not all the same.

I'll look into it

No0ne, 2025-02-01:
@bstrobl has implemented SGI support in ps2x2pico, maybe you reuse some parts: https://github.com/No0ne/ps2x2pico/pull/39

bstrobel, 2025-02-01:
Let me know if you need anything. Although I don"t have time to code at the moment I can still provide you with traces etc. I traced the communication of a few PS/2 keyboards with my SGI O2 using a logic analyzer to understand the protocol better. BTW the usually referred to documentation regarding scan code set 3 is not quite complete. You really need to trace it.

techomancer, 2025-02-01:
Also, there is definitely variability of PS/2 support between different SGI machines.
I have couple of Filco Majestouch 2 TKL (that has PS/2 backward compatibility), One partially works with Indigo 2, one doesn't at all.
But both work fine with O2. Haven't tried them yet with Indy or Octane.

bstrobel, 2025-02-03:
To be honest seeing the variety of problems regarding normal modern USB keyboards with normal USB communication I wouldn't put too much trust in the claimed PS/2 compatibility of them. Your really should test your SGIs with original 1990s and 2000s PS/2 keyboards. If they work you could trace the communication with a cheap $10 logic analyzer and use the code of ps2x2pico as a basis for implementing scancode set 3 support in HIDman. I guess the changes will be minor. I can support you with that a bit if you want.

Or you could just build a ps2x2pico yourself (investment of about $10 to $15) and try it out. Maybe (I even dare to say probably) it works out of the box.

techomancer, 2025-02-03:
I probably will, I ordered some level shifters, I also have DreamSourceLab logic analyzer so I can hook it up.
I just have too many projects pending ...

next68k, 2025-02-15:
I would like to help. Trying to get a Leopold FC900R working on my SGI O2.  I get very erratic behavior with this keyboard and a PS/2 adapter. Like keys randomly stop working and such. Board seems to work fine in USB mode on a mac or pc.  I don't know if it is a scancode issue or I need a different PS/2 adapter.

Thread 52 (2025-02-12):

DEC VT520 Incompatibility

xylobol, 2025-02-12:
Hello, I've recently put one of these together (parts ordered from https://retrohackshack.com/product/hidman-usb-keyboard-converter/), for use with a NiZ Plum X87 keyboard and my Digital Equipment Corporation VT520 terminal. Problem is, the mapping is pretty strange - the terminal is recognizing F10 as Print Screen and Ctrl as Caps Lock. The arrow keys don't seem to work either. Esc becomes numlock, and the terminal doesn't even seem to recognize F1-F8.

These older VT5XXs expect a pretty specific keyboard layout when using what DEC dubs a "PC keyboard" (see https://www.manualslib.com/manual/1200903/Digital-Equipment-Vt520.html?page=28#manual).

It's worth noting that the NiZ has a PS/2 mode that I've tested with a passive adapter, and gotten the same results with.

I would like to contribute patches to fix this incompatibility, or even just maintain a fork for this purpose, but I'm not sure where to start. I don't have any other devices that natively use PS/2 (I'm assuming I could get scancodes from the VT keyboard using a passive PS/2 to USB adapter, though).

Any pointers would be appreciated.

xylobol, 2025-02-12:
I forgot to note this in my original issue. I saw there's a "log HID data" option in the settings - want me to hook the terminal up to a computer, and attach a file after I press every key on the keyboard?

rasteri, 2025-02-12:
Grab the latest beta version and see if that changes anything - https://github.com/rasteri/HIDman/releases/tag/v1.1.5f

But a HID log would be useful, yeah.

What to do is, enable HID logging, then plug/unplug your USB keyboard so it captures the initialization. Also press some of the keys that are misbehaving (I don't need every key).

Try it again in advanced keyboard mode, too.

rasteri, 2025-02-12:
Also it would be useful to establish if it's the keyboard or the terminal that has the issue with hidman - if you have a regular ol PC you could try it on that

xylobol, 2025-02-12:
These are in this order:
1. up arrow
2. left arrow
3. down arrow
4. right arrow
5. F1
6. F2
7. F3
8. Esc

Unfortunately, I couldn't capture the replug - the VT520 briefly shuts off power through the PS/2 port when it detects a keyboard has been unplugged. Captured using 1.1.5f.

I don't have anything else with a PS/2 input, but my guess would be the terminal. I can test soon if a passive PS/2 -> USB adapter would work, and re-run these tests. If not, I can obtain a machine with native PS/2, but it might take a bit.

[dumpadv.txt](https://github.com/user-attachments/files/18771055/dumpadv.txt)
[hid-dump.txt](https://github.com/user-attachments/files/18771056/hid-dump.txt)

xylobol, 2025-02-12:
Something else notable is that the terminal makes a noise using its built-in speaker when it detects a keypress - the alphanumerics work totally normally and make the noise, but F1-F3 and the arrow keys (among others) *don't* make the noise, implying the terminal doesn't even know what to do with the signals it's getting.

rasteri, 2025-02-19:
Ah yeah, even the menu is corrupted. That's definitely an issue with the HIDman<>terminal connection rather than USB

Those PS2-to-USB adapters also produce corrupted output. HIDman does seem to have issues with a number of non-pc PS/2 devices. It's pending investigation, hopefully if I fix the ps2 adapters that'll fix stuff like your terminal too.

habys, 2025-03-28:
Thank you for opening this bug. I am interested in being able to use nicer keyboards with my VT520 and a VT525. I haven't received my adapters yet (based on the hope!) but please let me know if there is any thing I can do to help once I get them.

rasteri, 2025-04-20:
Yes that is very possible, the next version of the hidman firmware will have optional rate limiting. Also I've just been generally doing some work around troublesome ps/2 hosts so I think when 1.1.5 is finished it should work better with non-PC hosts

habys, 2025-07-18:
I had forgotten about this for a while. I see 1.1.6 released now. If anyone has any news please post, otherwise when I get a chance I'll test this (and perhaps try limited the data rate) and report back.

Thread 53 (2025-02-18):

Various Wireless Mice X, Y, Z Axis bug

writeguide6667, 2025-02-18:
I have tried all of these wireless mice connected to the HIDman and they seem to work somewhat, but all have erratic movement and or always lock the mouse cursor position to the bottom of the screen. the only mouse that i've tried that is fully functional in my possession is a wired USB Logitech B100 Mouse.

The offending wireless mice are as follows with their associated HIDlogs

[g304.txt](https://github.com/user-attachments/files/18853525/g304.txt)
[m187.txt](https://github.com/user-attachments/files/18853526/m187.txt)
[yichip.txt](https://github.com/user-attachments/files/18853524/yichip.txt)

1. Logitech G304 Lightspeed

2. Logitech M187 Mini Wireless Mouse

3. YICHIP Wireless Device "Generic Wireless Black Mouse"

writeguide6667, 2025-02-19:
with the current firmware, the G304 with advance USB mode off don't lock to the bottom of screen, but has that wierd jumping/resetting position erratic movement mentioned earlier.

YICHIP works properly with advanced USB mode off. the only strange issue is that right clicking the mouse button just makes the cursor drift to the right instead of opening the right click menu.

all three of these mouse do lock to the bottom of screen when enabling advanced mode USB.
this was tested on Windows 98 SE and mageia 9 linux.

with that being said, i'll try the new firmware to see if the m187 changes behavior with advanced USB mode ON or OFF.

writeguide6667, 2025-02-19:
i tested the new firmware. Both the M187 and Yichip wireless mice now work properly with advanced USB mode both ON and OFF.

The G304 still has problems with advanced USB mode ON with a slight behavior change with mouse cursor no longer locking to the bottom but instead flickering all over the desktop. it seems work okay with advanced USB mode off, however i'm still getting random left clicks and erratic cursor movement on occasion. this seems to happen when i'm just only moving the mouse around the desktop.

in total of wireless mice, i'm satisfied with the other two working fine.

rasteri, 2025-03-03:
Yeah the G304 is sending what are essentially corrupted packets when it's not running in advanced mode. It may not be possible to get it running in non-advanced mode.

If you have a chance, could you send me a HID log of the G304 in advanced mode? Plug it in and then move it around a bit and press the buttons some.

writeguide6667, 2025-03-04:
here is the HID log for the G304 with advanced USB mode on.

[G304.TXT](https://github.com/user-attachments/files/19078073/G304.TXT)

rasteri, 2025-03-08:
Aha, the G304 sends 12-bit X and Y coordinates, which I haven't tested fully yet.

I've bought a G304, found one on ebay for a fiver :)

writeguide6667, 2025-03-09:
the lightspeed G304 wireless mouse; when getting one used, you will probably want to connect to usb on a regular PC to test for accidental double clicking because the mouse may have worn out switches that may interfere with your tests.

rasteri, 2025-03-25:
So I bought a G304 and also get glitchy output. But it turns out the G304 I bought is fake - its vendor ID indicates it's made by Yichip.

So I looked up the vendor ID of your G304, and it's made by SEMITEK.

Can your G304 connect to Logitech G-Hub software? If not I suspect it's fake too.

writeguide6667, 2025-03-25:
So i tried the Logitech G-Hub suite, and yeah... it can't find the mouse, wow.

whats even worst is i did an usb device listing under linux and it shows up as an "SHARKOON Technologies GmbH 2.4GHz Wireless rechargeable vertical mouse [More&Better]" with usb ID 1ea7:0064

it indeed is a fake, which to my surprise because is quite humorous since i've just got to use this mouse as i had it sitting around for quite awhile in it's still new packaging bought off from amazon. Woops.

writeguide6667, 2025-03-25:
i've must of had real g304 at one point because i've bought this one to replace the old one because of the annoying double clicking, i never even thought of ever using their software as i assumed it was just bloatware.

rasteri, 2025-03-25:
what a strange turn of events! haha.

My mouse seems to be even more glitchy than yours, it knocks itself out of boot mode every time you rightclick (but not leftclick). bizarre.

I'm still gonna try to get hidman working with it though. If Windows can use it then hidman should be able to too.

writeguide6667, 2025-03-26:
all of these mice seem to work fine in both windows and linux when connected directly to the PC via USB connection.

it's just in the hidman where things get whonky. this unfortunately is going to get tricky when we have a bunch of devices pretending to be some something they aren't i.e. fake mice.

writeguide6667, 2025-05-20:
Hey again, just letting you know with the newly released 1.1.5 firmware from today has solve all the above issues, even all of my fake chinese USB mouse are now fully functional. i had ended up buying a logitech g305 from Micro center just last week to see if they are also vulnerable to selling fake branded computer peripherals and as it turns out the mouse i got was a real Logitech mouse. It even reports as such under USB HID info under Linux.

Now that all my computer mice work, The Micro center purchase became pointless. oh well... at least i got a free 128 SSD with the purchase.

So with that being said, i guess this issue can be closed unless someone else finds the exact same problems with the current HIDman firmware.

Closed 2025-05-21.

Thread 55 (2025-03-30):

More widespread case for AXP?

yarodin, 2025-03-30:
Is there analogue for this https://lincolnbinns.com/e-case-a-40mm-black.html  case for AXP on aliexpress etc?
It's  totally impossible to gets one at my location.

rasteri, 2025-03-30:
Evatron sells them under a different name if that helps at all : https://evatron.com/enclosures/aluminium-enclosures/aluminium-enclosures-re-series/reab40-aluminium-extrusion/

I can't find any on aliexpress though

nizmow, 2025-04-25:
I found these on element14 which fit perfectly: https://au.element14.com/multicomp/mcreas40/case-aluminium-40x63-5x30mm/dp/1549964

Not black though!

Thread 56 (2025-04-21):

Problem with PCB/Assembly (report from NextPCB)

yarodin, 2025-04-21:
I'm trying to order assembled Hidman AXP from NextPCB (the only service available at my location).
I took gerbers, centroid and BOM files from [https://github.com/rasteri/HIDman/tree/main/hardware/axp](https://github.com/rasteri/HIDman/tree/main/hardware/axp).
But suddenly I got error report from Design for Assembly (DFA) and I don't understand what's wrong and what should I do next.

[NextPCBDFAReportTR63009AA1.xlsx](https://github.com/user-attachments/files/19832380/NextPCBDFAReportTR63009AA1.xlsx)

[BOM_4_B-R63009AA1.xlsx](https://github.com/user-attachments/files/19832381/BOM_4_B-R63009AA1.xlsx)

yarodin, 2025-04-24:
Сommunication with PFA Team of NextPCB is continuing. According to their information the main problem with J1,J3 DIN-6 conn.

"For J3,J1, the difference and the dimension of the holes between the Gerber and datasheet is too big, so there is a big risk that the components can't be inserted in"

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

RoberMC, 2025-05-03:
That's because the footprint does not match the part, it seems it is for another kind of mini-din with more pins, but the correct Mini-Din 6 part should fit with some manual force, I had that issue myself. Usually manufacturers will complain about that if you tell them to asemble the through hole parts. It's better to assemble that part manually by yourself.

yarodin, 2025-05-03:
Yes, you are right. In BOM file DIN-6 connector with six pin on the PCB part: [https://www.lcsc.com/datasheet/lcsc_datasheet_2409302302_HOOYA-DIN-603_C7428703.pdf](HOOYA DIN-603),
whereas PCB designed for a slightly other type of connector (eight pins on th PCB part)

May be it will be a good idea to adjust Hidman PCB to exactly DIN-6 connectror from project BOM file?

In sum I ordered assembled devices without mounted DIN-6 connector from NextPCB. Interesting, but PCBWay sent to production exactly same files (gerbers, BOM, centroids) without any question. I will look to result ;)

rasteri, 2025-05-03:
Hey, I'll take a look at modifying the PCB to fit the footprint better. I guess I just never noticed the problem because the parts fit ok.

rasteri, 2025-05-03:
I used the footprint for 8 pin because I thought they were the same and I had a previous project using 8pin devices. Ah well, laziness fails me again...

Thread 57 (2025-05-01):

8bitdo retro bluetooth/2.4ghz keyboard works connected with USB but not wirelessly

keenerb, 2025-05-01:
Attached as USB it works perfectly.

Attached as wireless, I never see a link light on the 8bitdo keyboard but the hidman LED flashes as if it's receiving data, and the HID capture shows some sort of event intercepted but never see any characters entered.

[ASDF.txt](https://github.com/user-attachments/files/20003583/ASDF.txt)

The capture was started with device attached as USB, at "renumerating all ports" I had inserted the wireless dongle and switched to 2.4ghz mode.  I unplugged the USB cable around line 100 in the log output.

I hit the A key four or five times, and then the B and C keys once each.

rasteri, 2025-05-13:
Two things -

- Try the latest beta firmware (v1.15i) - https://github.com/rasteri/HIDman/releases/tag/v1.1.5i
- If that doesn't work, send me another log but this time unplug the wired keyboard before plugging the wireless in

keenerb, 2025-05-14:
[8BITDO.TXT](https://github.com/user-attachments/files/20208577/8BITDO.TXT)

I started debug mode with a wired keyboard and then unplugged it, and plugged in the 8bitdo wirelessly and typed A - J (or something along those line.)

When I reconnected the original keyboard to save the document, it would not work either.  I had to unplug the hidman from the computer and then re-connect to be able to save the document.

rasteri, 2025-05-14:
Yeah there's a bug in 1.1.5i where the log mode doesn't exit properly....

I'll look over your results.

keenerb, 2025-05-14:
Thanks.  It works fine using USB cable so it's not exactly a critical issue.

rasteri, 2025-05-17:
It seems from the logs that the simple USB mode on the dongle doesn't work. Try turning on "Advanced USB" in BOTH the Keyboard AND Mouse menus (a lot of devices don't like only one being turned on). See if that improves anything

vanfanel, 2025-05-20:
> It seems from the logs that the simple USB mode on the dongle doesn't work. Try turning on "Advanced USB" in BOTH the Keyboard AND Mouse menus (a lot of devices don't like only one being turned on). See if that improves anything

Hey Rasteri!
Another 8BitDo Retro Keyboard user here.
The keyboard works fine after activating the "Advanced USB" option.
If that's a valid solution (well, it works fine here) then this issue can be closed I believe.

rasteri, 2025-05-21:
I might contact 8bitdo and point out the bugs in their keyboard... not sure if there's anything they can do to update them now they're released though.

vanfanel, 2025-05-21:
> I might contact 8bitdo and point out the bugs in their keyboard... not sure if there's anything they can do to update them now they're released though.

Well, these 8bitdo keyboards can have their firmware updated (with very poor quality Windows software instead of proper fwupd support, but well...) so yes, please do contact them on the issues. I tried but I lack patience with their poor support denying GNU/Linux existence.

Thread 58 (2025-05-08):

KVMs/USB switches not working

GuerreroNinja, 2025-05-08:
I have a Hidman AXP with the latest firmware flashed and a Tinyllama 2 device (which includes a Hidman for USB-PS2 conversion). I tried several KVM/USB switches as I share the same keyboard and mouse between machines. However, both with the Hidman device and Tinyllama, seems the KVM is not recognized somehow and keyboard/mouse don't work. I tried 2 USB 3.0 KVMs and 1 USB 2.0 KVM with no luck.

Firmware:  hidman_axp_v1.1.4.hex flashed with Windows tool.

rasteri, 2025-05-08:
try v1.1.5h - we made some bugfixes regarding KVMs - https://github.com/rasteri/HIDman/releases/tag/v1.1.5h

GuerreroNinja, 2025-05-08:
Ok, tested. Now it works, the new firmware fixed it. Thank you!!

Closed 2025-05-08.

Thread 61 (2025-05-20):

Recovering HIDman from bad flashing

vanfanel, 2025-05-20:
Hello there @rasteri

After following the flashing instructions for GNU/Linux, I got a message on the console about not being able to verify the firmware flash and now I get an error about hardware not found.
The HIDman now shows fixed green light and doesn't work (doesn't show any LED activity when sending USB keystrokes).

I am sure it was a bad flashing.

Is there a way to recover from that?
Like, I see there are three pins on the board labeled "J5": maybe I could try using dupont cables and a programmer, but what's each pin for and what software should I use?

(Luckily I have more HIDmans so I can use it anyway... but I wouldn't like to trash a recoverable board!)

Thanks!

Closed 2025-05-20.

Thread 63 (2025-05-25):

Feature request:  Basic joystick keystroke remapping via built-in menu

keenerb, 2025-05-25:
It would be nice to be able to access a menu under 3. Game that would prompt for something along these lines:

Up: <accepts single keypress>
Down: <accepts single keypress>
Left: <accepts single keypress>
Right: <accepts single keypress>

Button 1: <accepts single keypress>
Button 2: <accepts single keypress>

So you could access the menu and do something like:

Up: w
Down: a
Left: s
Right: d

Button 1: ctrl
Button 2: alt

and have the joystick mapped to those keyboard keypresses.

rasteri, 2025-05-27:
Yes this is a feature that has been on my mind for some time. Essentially all the back-end code is there it just needs the menu to be coded.

RoberMC, 2025-06-27:
It would be better if Hidman could be accessed from the computer using serial port to configure the remaps. This way one could launch a game with a batch file sending the remap and then launching the game's executable. I haven't checked the diagram so i don't know if serial receive pins are wired to the MCU though.

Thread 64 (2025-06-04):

Mouse doesn't work through passive splitter

SelfRef, 2025-06-04:
Hi,

I got my order from PCBway with boards and after flashing latest firmware 1.1.6, everything works great when connected directly - keyboard through rear mDIN, mouse through front mDIN and mouse through COM port.

However, I got this cheap PS/2 splitter [from here](https://www.aliexpress.com/item/1005007116827185.html?spm=a2g0o.order_list.order_list_main.77.46a41802uD4OIo), I tested it in modern PC with one PS/2 port (it works) but after connecting to rear mDIN of HIDman (the one for keyboard), the keyboard does work, but mouse isn't even recognized at all. From README I see this setup is supposed to work and for convenience it would be very handy for me to connect this way, but I'm not sure why it doesn't work. No settings were changed in the built-in config menu.

rasteri, 2025-06-04:
As of version 1.1.5 you need to enable "PS2 aux output" in the advanced
menu. The extra outputs were upsetting some motherboards.

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

SelfRef, 2025-06-04:
Oh, so this is an option for that. In modern PC it's named "PS/2 splitter support" in BIOS, a little more descriptive.

Thank you, it works perfectly. I may suggest adding this option to README in case anyone will try to use this feature 😃

Closed 2025-06-04.

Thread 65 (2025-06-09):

Game pad as mouse functionality lost 1.14 to 1.16

bri0528, 2025-06-09:
Updated FW from (as-received) v1.14 to 1.16.  When enabled, my ps4 wired gamepad doesn't have the gamepad as mouse functionality (was working with v1.14).

Also, not sure if this has been requested previously, but having a sensitivity / gain setting for gamepad-as-mouse would be a great added feature.

Thanks!

rasteri, 2025-06-10:
Oh weird, I definitely tested it with my PS4 controller.

You definitely have the option enabled in the game controller menu? It resets when you reflash firmware.

I'll test again over here tonight.

bri0528, 2025-06-10:
My PS/2 cable might have not been inserted completely into my PC.  I switch to a regular PS/2 mouse to verify functionality and then re-inserted the cable from the HIDman, and it appears to be working now.  Apologies!   Mouse sensitivity is much better now also compared to 1.14.

Awesome device, thank you!

Closed 2025-06-10.

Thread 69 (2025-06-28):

Keyboard not detected on cold boot.

dzlia, 2025-06-28:
Assuming here that there is a single keyboard plugged into HIDman.

Sometimes (regularly, rather happens than not) on cold start the already plugged-in keyboard is not detected by BIOS during post. In all cases reset helps to make the keyboard visible. For mouse it works fine, if I don't play with modes and plugging/unplugging devices.
Cold boot with USB Type A <-> Type A cable plugged (for powering HIDman) solves the problem too.

The problems happens with at least 3 keyboards that I used for testing.

I suspect that it is an initialisation data race, where BIOS happen to check if the keyboard is present before HIDman starts, and then it is too late. However, I won't insist on this guess.

The computer I tested on is:
Pentium III 667/133, Mobo Asus P3V133 (VIA Apollo Pro 133), PS/2 for mouse and keyboard.

Upgrading to the latest firmware (1.1.6) didn't change this behaviour.

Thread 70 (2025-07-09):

Not been able to use Mouse + Keyboard (Kensigton Track Ball)

rjorge99, 2025-07-09:
Firmware: 1.6
Mode: Hard Blue Light

I have connected a keyboard via USB to one of the HIDMAN Usb ports, and the PS2  port (the one on the back part of the USB Ports) to my computer PS2 port (It has a Ps2 Combined Port)

It works great. But for some reason, I have tried different mice and none of them work.

Not sure if the way I am connecting the keyboard and mouse is the correct one ?

The main reason of using Hidman is because at work we dont have access to the usb ports of the computer, so I was not able to use my keyboards , until I found out about Hidman.

I attach the Log HID Data information. (It recorded information when scrolling and moving the  mouse, and clickin, but nothing was reflected on the screen, the mouse is a Kensington Track Ball.... other mice were used with the same result)

Not sure if this is the information you need. If you need more information, please let me know.

Thanks

[log hid data.txt](https://github.com/user-attachments/files/21133320/log.hid.data.txt)

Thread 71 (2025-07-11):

USB Hub issues and diagnose, It's "almost" working.

RoberMC, 2025-07-11:
Hello, first congratulations for this amazing device and your great work, I got it yesterday and I am having Issues with a pretty common USB HUB, Here's what I observed and I hope my findings help making it more stable.

The USB HUB is based on the Terminus FE2.1 chip (USB2.0, 7 ports)

- When the HUB is connected the remaining native hidman port starts behaving erratically, it skips key presses or repeat keys randomly
- Devices connected to the HUB do not work, nothing is registered, blue light does not blink.
- Enter the Menu - Advanced - Log HID Data, do a Rescan.
- After the rescan completes everything connected to the HUB start working 100% perfectly while the native HIDMAN port keeps behaving erratically
- If the HUB is unplugged the native port starts to work fine again.
- If you plug again the HUB, there's 80% chance devices connected to it will not be recognized, after a rescan they will be detected again.
- Native Hidman USB ports will never work fine as long as the hub is connected to the other port.

The devices I have connected are:
HIDMAN USB1: Noname USB mechanical Keyboard
HIDMAN USB2: FE2.1 HUB ---> Logitech Unifying Receiver (Logitech K400 Plus keybd+trackpad)

I attached the log when doing a rescan and the devices on the hub pass from not being recognized to be recognized.

I hope this information is helpful, thank you for the hard work you put into this.

[HIDMAN_LOG1.TXT](https://github.com/user-attachments/files/21184848/HIDMAN_LOG1.TXT)

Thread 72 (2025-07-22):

Unable to upload firmware

xinteksik, 2025-07-22:
I ordered the module through the link on PCBWay. It arrived today, and I’m trying to upload the firmware, but the device is not being recognized. I'm testing it according to the instructions on Windows 11. What else can I do, how can I upload the firmware alternatively, or what should I check? Thank you for your support and help.

rasteri, 2025-07-23:
Yeah I think some chips come from the factory without bootloader enabled for some reason.

I should really put something about that in the readme

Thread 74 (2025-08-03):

PS2 combo port not recieving both USB devices

footnmouth5, 2025-08-03:
I have multiple old laptops (Dell XPi CD and Toshiba Portege 660CDT) they have a combo PS2 port. Using a single male to male PS2 extension cable I plug it into the HIDman. In the two HIDman USB ports I have a 8bitdo Pro2 controller and a Kensington trackball mouse. Both USB devices will not work at the same time. If I plug the PS2 cable into the the keyboard PS2 port on the HIDman (purple) the Kensington mouse will work but not the Pro2 controller. If I then plug the PS2 cable into the mouse PS2 port on the HIDman (green) then the Pro2 controller will work but not the Kensignton mouse. All the while the blue led on the HIDman will flash with inputs regardless if the laptops are receiving the inputs.
I am unsure if this is expected behavior.

Further experimentation I did was to introduce a PS2 splitter plugged into the laptop's PS2 combo port. I then plugged both of the split PS2 cables into both PS2 ports on the HIDman. I still could not get input from both USB devices simultaneously. Testing further it seemed that the HIDman would only work with the keyboard (purple) cable from the PS2 splitter and again if I alternated the ports I plugged the purple cable into on the HIDman only one of the two USB devices would work.
I am unsure if this is expected behavior.
Is it not possible to use two USB devices at the same time using a PS2 combo port via HIDman?

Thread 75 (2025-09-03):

Onikuma Gaming Mouse CW917 compatibility issues.

GuruSR, 2025-09-03:
Firmware 1.1.6.
Mouse configuration is No for both Adv and Intellimouse.  If either are Yes, the mouse fails to do basic work (mouse buttons work though).

LRM and movement work with Adv and Intellimouse both at No.

This is a basic 5 button mouse (gaming'ish), 3600/2400/1800/1200 DPI.  LRM, wheel and 2 side buttons.

Their website is:  www.onikumagaming.com

[MouseInfo.txt](https://github.com/user-attachments/files/22118911/MouseInfo.txt)

This is going to be plugged into a PS/2 KVM to allow me to use other mice.  The above mouse does see some lag if you move it around a lot (fast), visually can see when I stop the mouse, the pointer is still moving.

I have an old usb to PS/2 adapter (from a Microsoft PS/2 mouse kit), that this mouse does work directly with on the KVM, but only the mouse buttons and movement (no wheel).  I didn't see any lag this way.

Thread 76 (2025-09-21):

Problem with mouse detection on PS/2 ZX Evolution

yarodin, 2025-09-21:
I got a strange problem with all my usb mouses connected through HIDman to ps/2 port on ZX Evolution.
ZX Evolution show mouse cursor on display: mouse detected. But in HIDman "PS2 mouse status":
Type           0
Rate           0
Resolution     0
Scaling        0
Data reporting 0

Command buffer

00 00 00 00 00 00 00 00 00 00 00 00 00 00 00 00
00 00 00 00 00 00 00 00 00 00 00 00 00 00 00 00

Mouse not working, but led on HIDman is flashing when mouse movement or key pressing.

From time time (when i'm changing any option through HIDman menu and then hard reset ZX Evolution mostly) mouse start working and works until power off ZX Evolution with HIDMan.

Type           3
Rate           100
Resolution     1
Scaling        0
Data reporting 1

Command buffer

F4 01 E8 F4 00 E8 F4 64 F3 E6 F2 50 F3 64 F3 C8
F3 FF FF FF 00 00 00 00 00 00 00 00 00 00 00 00

- All my ps/2 mouses working without any issue on ZX Evolution.
- All my usb mouses working without any issue  connected through HIDman to PC with ps/2 ports.
- All my usb keyboards working absolutely stable connected through HIDman to ps/2 port on ZX Evolution.

It seems problem with ps/2 mouse init/detect stage on HIDman. Timings-delays maybe.

I'm spent a lot of time trying to get logs through HIDMan COM-port (Serial Log - Yes). But without succes. Is any step by step guide?

yarodin, 2025-10-04:
After some investigation turned out ZX Evolution's AVR trying to detect PS/2 mouse and keyboard simultaneously. It is for this reason I got strange bug with USB mouse detection connected through HIDman. The firmware of AVR was changed to detect PS/2 keyboard first and then mouse and problem has gone.

[https://github.com/tslabs/zx-evo-old/commit/faf95c1a97ad2422c7ef303013204593cf0f797b](Commit to Double-Conf with fix)

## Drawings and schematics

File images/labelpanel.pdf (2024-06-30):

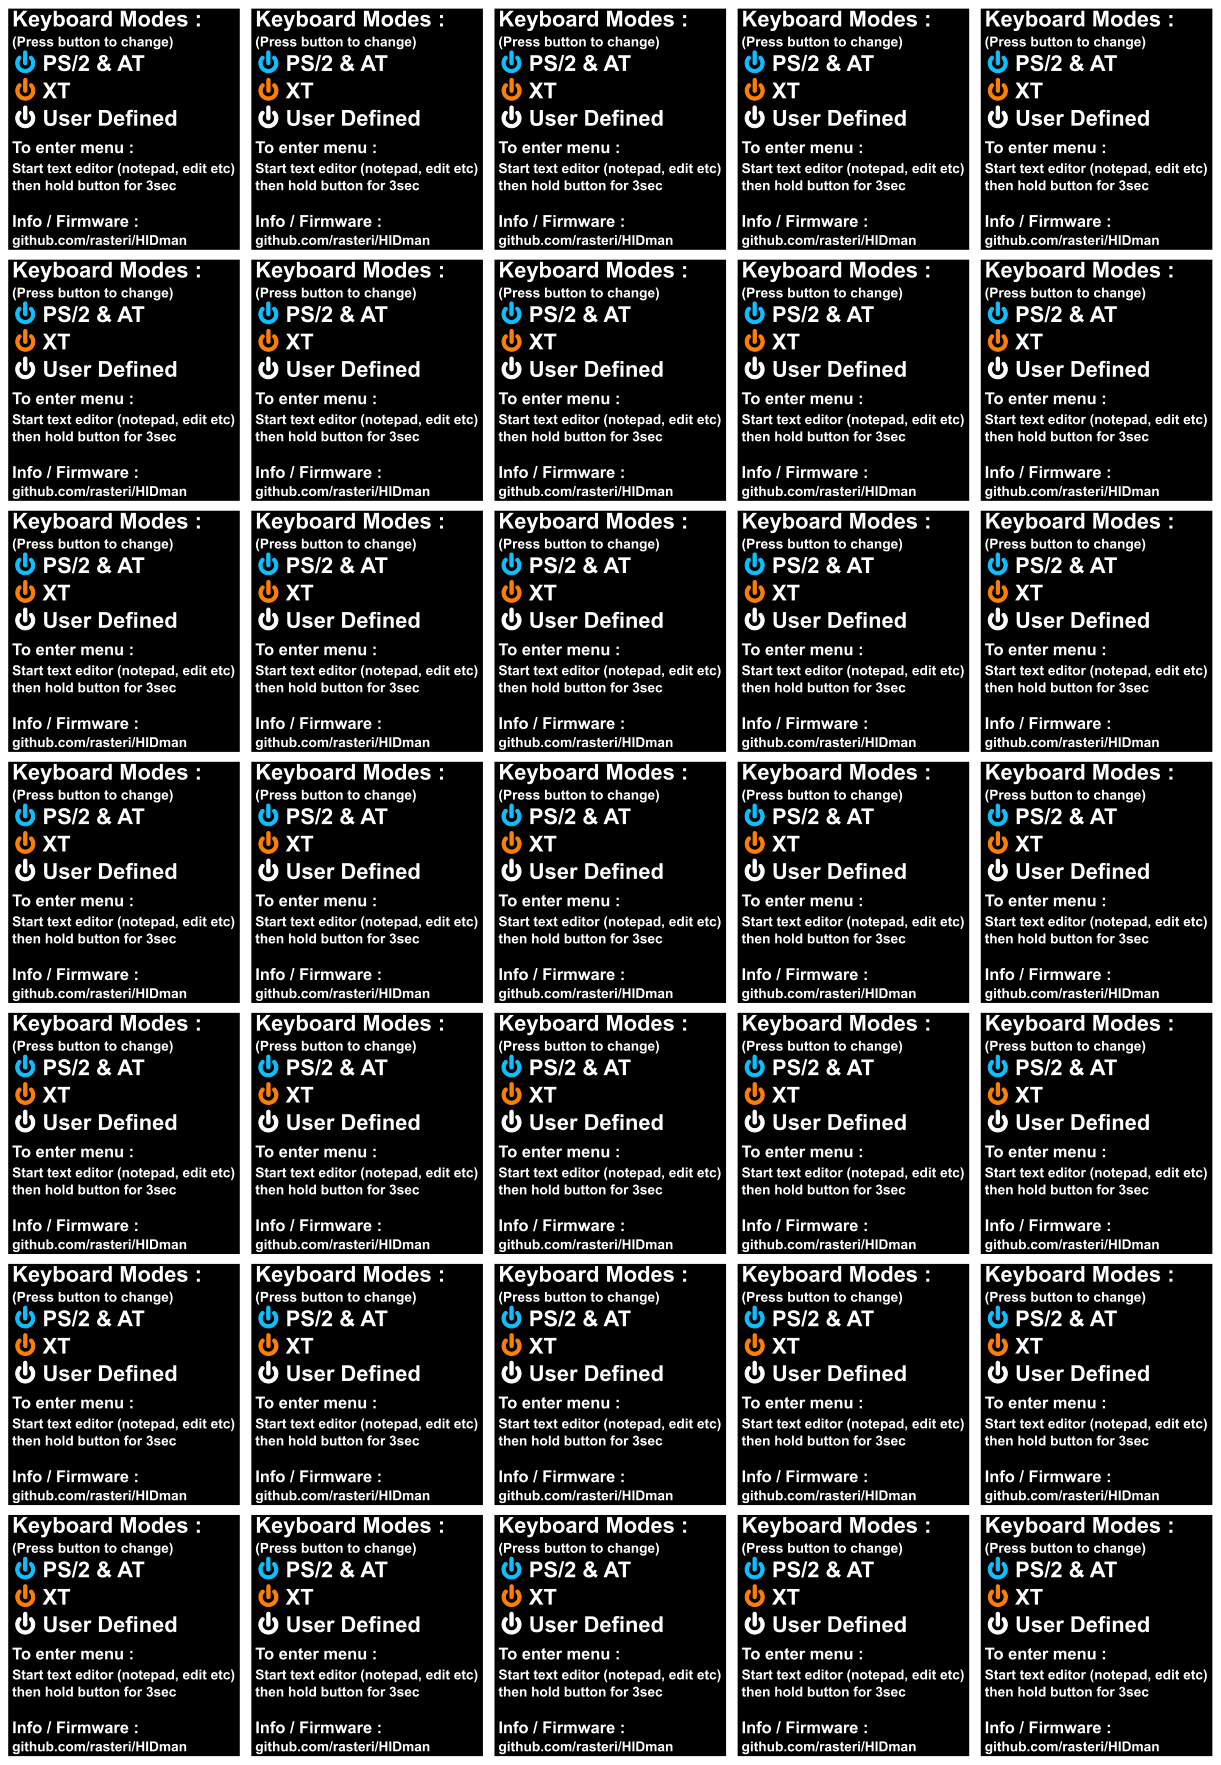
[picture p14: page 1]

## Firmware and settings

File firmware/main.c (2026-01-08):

#include <stdio.h>
#include <stdint.h>
#include <stdbool.h>
#include <string.h>
#include "ch559.h"
#include "usbhost.h"
#include "uart.h"
#include "ps2protocol.h"
#include "ps2.h"
#include "parsedescriptor.h"
#include "menu.h"
#include "mouse.h"
#include "xt.h"
#include "amstrad.h"
#include "pwm.h"
#include "keyboardled.h"
#include "dataflash.h"
#include "settings.h"
#include "system.h"

uint8_t UsbUpdateCounter = 0;

void EveryMillisecond(void) {

	// Soft watchdog is to get around the fact that the real watchdog runs too fast
	SoftWatchdog++;
	if (SoftWatchdog > 5000) {
		// if soft watchdog overflows, just go into an infinite loop and we'll trigger the real watchdog
		DEBUGOUT("Soft overflow\n");
		while(1);
	}

	// otherwise, reset the real watchdog
	WDOG_COUNT = 0x00;
	// every 4 milliseconds (250hz), check one or the other USB port (so each gets checked at 125hz)
	if (UsbUpdateCounter == 4)
		s_CheckUsbPort0 = TRUE;
	else if (UsbUpdateCounter == 8){
		s_CheckUsbPort1 = TRUE;
		UsbUpdateCounter = 0;
	}

	UsbUpdateCounter++;
	

	// handle serial mouse
	#if defined(OPT_SERIAL_MOUSE)
		static uint8_t RTSHighCounter = 0;
		static __xdata uint8_t serialMousePrevMode = SERIAL_MOUSE_MODE_OFF;

		// High toggle (> 50ms) of RTS (P0.4) means host is resetting mouse.  Wait until falling edge and send mouse identification.

		if (P0 & 0b00010000) { // RTS is high (mouse is resetting)
			if (serialMouseMode != SERIAL_MOUSE_MODE_RESET) {
				serialMousePrevMode = serialMouseMode;
				serialMouseMode = SERIAL_MOUSE_MODE_RESET;
			}
			if (RTSHighCounter < 255) RTSHighCounter++;
			
		} else { // RTS is low
		if (serialMouseMode == SERIAL_MOUSE_MODE_RESET) {
				if (RTSHighCounter > 50) { // Check if RTS was high long enough to indicate reset...
					serialMouseMode = SERIAL_MOUSE_MODE_INIT;
				} else {
					serialMouseMode = serialMousePrevMode;
				}
				RTSHighCounter = 0;
			}
		}
	#endif

	// check the button
	inputProcess();

	// Deal with BAT (which requires a delay)

	if (KeyBatCounter){
		KeyBatCounter--;
		if (!KeyBatCounter)
			SimonSaysSendKeyboard(KEY_BATCOMPLETE);
	}

	if (MouseBatCounter){
		MouseBatCounter--;
		if (!MouseBatCounter) {
			SimonSaysSendMouse1(0xAA); // POST OK
			SimonSaysSendMouse1(0x00); // Squeek Squeek I'm a mouse
		}
	}

	if (MenuRateLimit) {
		MenuRateLimit--;
	}


	// Turn current LED on if we haven't seen any activity in a while
	if (LEDDelayMs == 255)
	{
		// on "until further notice", do nothing
	}
	else if (LEDDelayMs) {
		LEDDelayMs--;
	} else {
#if defined(BOARD_MICRO)
		SetPWM2Dat(0x10);
#elif defined (BOARD_PS2)
		P0 |= 0b01110000;

		switch (FlashSettings->KeyboardMode) {
			case MODE_PS2:
				// blue
				P0 &= ~0b01000000;
			break;
			case MODE_XT:
				// orange
				P0 &= ~0b00010000;
				P0 &= ~0b00100000;
			break;
			case MODE_AMSTRAD:
				// white
				P0 &= ~0b00010000;
				P0 &= ~0b00100000;
				P0 &= ~0b01000000;
			break;
		}

#else
			SetPWM1Dat(0x00);
			SetPWM2Dat(0x00);
			T3_FIFO_L = 0;
			T3_FIFO_H = 0;

			switch (FlashSettings->KeyboardMode){
				case MODE_PS2:
					// blue
					T3_FIFO_L = 0xFF;
					T3_FIFO_H = 0;
				break;
				case MODE_XT:
					// orange
					SetPWM2Dat(0x10);
					SetPWM1Dat(0x40);
				break;
				case MODE_AMSTRAD:
					// white
					SetPWM1Dat(0x30);
					SetPWM2Dat(0x20);
					T3_FIFO_L = 0x3F;
					T3_FIFO_H = 0;
				break;

			}
#endif
	}
}



// timer should run at 48MHz divided by (0xFFFF - (TH0TL0))
// i.e. 60khz
void mTimer0Interrupt(void) __interrupt(INT_NO_TMR0)
{

	if (OutputsEnabled) {

		switch (FlashSettings->KeyboardMode) {
			case (MODE_PS2):
				PS2ProcessPort(PORT_KEY);
				break;

			case (MODE_XT):
				XTProcessPort();
				break;

			case (MODE_AMSTRAD):
				AmstradProcessPort();
				break;
		}

		// May as well do this even in XT mode, can't hurt
		PS2ProcessPort(PORT_MOUSE);

		// Handle keyboard typematic repeat timers
		// (divide timer down to 15KHz to make maths easier)
		static uint8_t repeatDiv = 0;
		if (++repeatDiv == 4) {
			repeatDiv = 0;
			RepeatTimer();
		}
	}

	static uint8_t msDiv = 0;
	if (++msDiv == 60) {
		msDiv = 0;
		EveryMillisecond();
	}

}

int main(void)
{
	bool WatchdogReset = 0;

	// Watchdog happened, go to "safe mode"
	if (!(PCON & bRST_FLAG0) && (PCON & bRST_FLAG1)){
		WatchdogReset = 1;
	}

	GPIOInit();

	//delay a bit, without using the builtin functions
	UsbUpdateCounter = 255;
	while (--UsbUpdateCounter);

#if defined(OSC_EXTERNAL)
	if (!(P3 & (1 << 4))) runBootloader();
#endif

	ClockInit();
    mDelaymS(500);   
	
#if !defined(BOARD_MICRO)
	InitUART0();
#endif

	InitUsbData();
	InitUsbHost();

	InitPWM();

	InitPS2Ports();

	// timer0 setup
	TMOD = (TMOD & 0xf0) | 0x02; // mode 1 (8bit auto reload)
	TH0 = 0xBD;					 // 60khz

	TR0 = 1; // start timer0
	ET0 = 1; //enable timer0 interrupt;

	EA = 1;	 // enable all interrupts

#if defined(OPT_SERIAL_MOUSE)
	uint32_t serialMouseBps = 1200; // can do 19200 with custom mouse driver
	CH559UART1Init(20, 1, 1, serialMouseBps, 8);
#endif

	memset(SendBuffer, 0, 255);
	memset(MouseBuffer, 0, MOUSE_BUFFER_SIZE);

	if (WatchdogReset) DEBUGOUT("Watchdog reset detected (%x), entering safemode\n", PCON);

	InitSettings(WatchdogReset);

	// enable watchdog
	WDOG_COUNT = 0x00;
	SAFE_MOD = 0x55;
	SAFE_MOD = 0xAA;
	GLOBAL_CFG |= bWDOG_EN;

	WDOG_COUNT = 0x00;

	//while(1);

	OutputsEnabled = 1;

	DEBUGOUT("ok\n");

	// after 750ms output a BAT OK code on keyboard and mouse
	// there's a 500ms delay earlier so do 250 now
	MouseBatCounter = 250;
	KeyBatCounter = 250;

	// main loop
	while (1)
	{
		// reset watchdog
		SoftWatchdog = 0;
		if (MenuActive)
			Menu_Task();
		ProcessUsbHostPort();
		HandleMouse();
		ProcessKeyboardLed();
		HandleRepeats();
		//P0 ^= 0b00100000;
		
	}
}

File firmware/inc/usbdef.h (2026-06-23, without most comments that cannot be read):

#ifndef __USB_DEF__
#define __USB_DEF__

#ifdef __cplusplus
extern "C" {
#endif

/*----- USB constant and structure define --------------------------------*/

/* USB PID */
#ifndef USB_PID_SETUP
#define USB_PID_NULL            0x00    /* reserved PID */
#define USB_PID_SOF             0x05
#define USB_PID_SETUP           0x0D
#define USB_PID_IN              0x09
#define USB_PID_OUT             0x01
#define USB_PID_ACK             0x02
#define USB_PID_NAK             0x0A
#define USB_PID_STALL           0x0E
#define USB_PID_DATA0           0x03
#define USB_PID_DATA1           0x0B
#define USB_PID_PRE             0x0C
#endif

/* USB standard device request code */
#ifndef USB_GET_DESCRIPTOR
#define USB_GET_STATUS          0x00
#define USB_CLEAR_FEATURE       0x01
#define USB_SET_FEATURE         0x03
#define USB_SET_ADDRESS         0x05
#define USB_GET_DESCRIPTOR      0x06
#define USB_SET_DESCRIPTOR      0x07
#define USB_GET_CONFIGURATION   0x08
#define USB_SET_CONFIGURATION   0x09
#define USB_GET_INTERFACE       0x0A
#define USB_SET_INTERFACE       0x0B
#define USB_SYNCH_FRAME         0x0C
#endif

/* USB hub class request code */
#ifndef HUB_GET_DESCRIPTOR
#define HUB_GET_STATUS          0x00
#define HUB_CLEAR_FEATURE       0x01
#define HUB_GET_STATE           0x02
#define HUB_SET_FEATURE         0x03
#define HUB_GET_DESCRIPTOR      0x06
#define HUB_SET_DESCRIPTOR      0x07
#endif

/* USB HID class request code */
#ifndef HID_GET_REPORT
#define HID_GET_REPORT          0x01
#define HID_GET_IDLE            0x02
#define HID_GET_PROTOCOL        0x03
#define HID_SET_REPORT          0x09
#define HID_SET_IDLE            0x0A
#define HID_SET_PROTOCOL        0x0B
#endif

/* HID Report Types */
#define HID_REPORT_INPUT                0x01
#define HID_REPORT_OUTPUT               0x02
#define HID_REPORT_FEATURE              0x03


/* Bit define for USB request type */
#ifndef USB_REQ_TYP_MASK
#define USB_REQ_TYP_IN          0x80            /* control IN, device to host */
#define USB_REQ_TYP_OUT         0x00            /* control OUT, host to device */
#define USB_REQ_TYP_READ        0x80            /* control read, device to host */
#define USB_REQ_TYP_WRITE       0x00            /* control write, host to device */
#define USB_REQ_TYP_MASK        0x60            /* bit mask of request type */
#define USB_REQ_TYP_STANDARD    0x00
#define USB_REQ_TYP_CLASS       0x20
#define USB_REQ_TYP_VENDOR      0x40
#define USB_REQ_TYP_RESERVED    0x60
#define USB_REQ_RECIP_MASK      0x1F            /* bit mask of request recipient */
#define USB_REQ_RECIP_DEVICE    0x00
#define USB_REQ_RECIP_INTERF    0x01
#define USB_REQ_RECIP_ENDP      0x02
#define USB_REQ_RECIP_OTHER     0x03
#endif

/* USB request type for hub class request */
#ifndef HUB_GET_HUB_DESCRIPTOR
#define HUB_CLEAR_HUB_FEATURE   0x20
#define HUB_CLEAR_PORT_FEATURE  0x23
#define HUB_GET_BUS_STATE       0xA3
#define HUB_GET_HUB_DESCRIPTOR  0xA0
#define HUB_GET_HUB_STATUS      0xA0
#define HUB_GET_PORT_STATUS     0xA3
#define HUB_SET_HUB_DESCRIPTOR  0x20
#define HUB_SET_HUB_FEATURE     0x20
#define HUB_SET_PORT_FEATURE    0x23
#endif

/* Hub class feature selectors */
#ifndef HUB_PORT_RESET
#define HUB_C_HUB_LOCAL_POWER   0
#define HUB_C_HUB_OVER_CURRENT  1
#define HUB_PORT_CONNECTION     0
#define HUB_PORT_ENABLE         1
#define HUB_PORT_SUSPEND        2
#define HUB_PORT_OVER_CURRENT   3
#define HUB_PORT_RESET          4
#define HUB_PORT_POWER          8
#define HUB_PORT_LOW_SPEED      9
#define HUB_C_PORT_CONNECTION   16
#define HUB_C_PORT_ENABLE       17
#define HUB_C_PORT_SUSPEND      18
#define HUB_C_PORT_OVER_CURRENT 19
#define HUB_C_PORT_RESET        20
#endif

/* USB descriptor type */
#ifndef USB_DESCR_TYP_DEVICE
#define USB_DESCR_TYP_DEVICE    0x01
#define USB_DESCR_TYP_CONFIG    0x02
#define USB_DESCR_TYP_STRING    0x03
#define USB_DESCR_TYP_INTERF    0x04
#define USB_DESCR_TYP_ENDP      0x05
#define USB_DESCR_TYP_QUALIF    0x06
#define USB_DESCR_TYP_SPEED     0x07
#define USB_DESCR_TYP_OTG       0x09
#define USB_DESCR_TYP_HID       0x21
#define USB_DESCR_TYP_REPORT    0x22
#define USB_DESCR_TYP_PHYSIC    0x23
#define USB_DESCR_TYP_CS_INTF   0x24
#define USB_DESCR_TYP_CS_ENDP   0x25
#define USB_DESCR_TYP_HUB       0x29
#endif

/* USB device class */
#ifndef USB_DEV_CLASS_HUB
#define USB_DEV_CLASS_RESERVED  0x00
#define USB_DEV_CLASS_AUDIO     0x01
#define USB_DEV_CLASS_COMMUNIC  0x02
#define USB_DEV_CLASS_HID       0x03
#define USB_DEV_CLASS_MONITOR   0x04
#define USB_DEV_CLASS_PHYSIC_IF 0x05
#define USB_DEV_CLASS_POWER     0x06
#define USB_DEV_CLASS_PRINTER   0x07
#define USB_DEV_CLASS_STORAGE   0x08
#define USB_DEV_CLASS_HUB       0x09
#define USB_DEV_CLASS_VEN_SPEC  0xFF
#endif
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

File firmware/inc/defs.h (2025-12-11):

#ifndef __DEFS_H__
#define __DEFS_H__
#include <stdint.h>
#include <stdbool.h>
#include <string.h>
#include "type.h"
#include "andyalloc.h"
#include "linkedlist.h"

#if defined(BOARD_AXP)
	#define OPT_SERIAL_MOUSE
#endif

//packet id
#define ID_USB_KEYBOARD   0xA0
#define ID_USB_MOUSE      0xA1
#define ID_PS2_KEYBOARD   0xA2
#define ID_PS2_MOUSE      0xA3
#define ID_LED_STATUS     0xA4
#define ID_QUERY_ONLINE   0xA5
#define ID_SWITCH         0xA6

//data length
#define KEYBOARD_LEN  8
#define MOUSE_LEN     4
#define LED_LEN       1
#define ONLINE_LEN    1
#define SWITCH_LEN    1

//led status pos
#define NUM_LOCK_POS  0
#define CAP_LOCK_POS  1
#define SCROLL_LOCK_POS 2

//online 
#define STATUS_ONLINE 1
#define STATUS_OFFLINE 0

//switch
#define SWITCH_IN     1
#define SWITCH_OUT    0



#define ROOT_HUB_COUNT 2

#define MAX_EXHUB_PORT_COUNT 4
#define EXHUB_PORT_NONE 0xff
#define MAX_INTERFACE_COUNT 4
#define MAX_ENDPOINT_COUNT 4
#define MAX_EXHUB_LEVEL 1
#define ENDPOINT_OUT 0
#define ENDPOINT_IN 1

#define ERR_SUCCESS 0x00
#define ERR_USB_CONNECT 0x15
#define ERR_USB_DISCON 0x16
#define ERR_USB_BUF_OVER 0x17
#define ERR_USB_DISK_ERR 0x1F
#define ERR_USB_TRANSFER 0x20
#define ERR_USB_UNSUPPORT 0xFB
#define ERR_USB_UNKNOWN 0xFE

#define ROOT_DEVICE_DISCONNECT 0
#define ROOT_DEVICE_CONNECTED 1
#define ROOT_DEVICE_FAILED 2
#define ROOT_DEVICE_SUCCESS 3

/*#define DEV_TYPE_KEYBOARD   ( USB_DEV_CLASS_HID | 0x20 )
#define DEV_TYPE_MOUSE      ( USB_DEV_CLASS_HID | 0x30 )
#define DEV_TYPE_JOYSTICK      ( USB_DEV_CLASS_HID | 0x40 )
#define DEV_TYPE_GAMEPAD      ( USB_DEV_CLASS_HID | 0x50 )*/

#define HID_SEG_KEYBOARD_MODIFIER_INDEX 0
#define HID_SEG_KEYBOARD_VAL_INDEX 1
#define HID_SEG_BUTTON_INDEX 2
#define HID_SEG_X_INDEX 3
#define HID_SEG_Y_INDEX 4
#define HID_SEG_WHEEL_INDEX 5

#define REPORT_USAGE_PAGE 0x04
#define REPORT_USAGE 0x08
#define REPORT_LOCAL_MINIMUM 0x14
#define REPORT_LOCAL_MAXIMUM 0x24
#define REPORT_PHYSICAL_MINIMUM 0x34
#define REPORT_PHYSICAL_MAXIMUM 0x44
#define REPORT_USAGE_MINIMUM 0x18
#define REPORT_USAGE_MAXIMUM 0x28

#define TYPE_MAIN 0
#define TYPE_GLOBAL 1
#define TYPE_LOCAL 2

#define REPORT_UNIT 0x64
#define REPORT_INPUT 0x80
#define REPORT_OUTPUT 0x90
#define REPORT_FEATURE 0xB0

#define REPORT_REPORT_SIZE 0x74
#define REPORT_REPORT_ID 0x84
#define REPORT_REPORT_COUNT 0x94

#define REPORT_COLLECTION 0xA0
#define REPORT_COLLECTION_END 0xC0

#define REPORT_USAGE_UNKNOWN 0x00
#define REPORT_USAGE_POINTER 0x01
#define REPORT_USAGE_MOUSE 0x02
#define REPORT_USAGE_RESERVED 0x03
#define REPORT_USAGE_JOYSTICK 0x04
#define REPORT_USAGE_GAMEPAD 0x05
#define REPORT_USAGE_KEYBOARD 0x06
#define REPORT_USAGE_KEYPAD 0x07
#define REPORT_USAGE_MULTI_AXIS 0x08
#define REPORT_USAGE_SYSTEM 0x09

#define REPORT_USAGE_X 0x30
#define REPORT_USAGE_Y 0x31
#define REPORT_USAGE_Z 0x32
#define REPORT_USAGE_Rx 0x33
#define REPORT_USAGE_Ry 0x34
#define REPORT_USAGE_Rz 0x35
#define REPORT_USAGE_WHEEL 0x38
#define REPORT_USAGE_HATSWITCH 0x39

#define REPORT_USAGE_PAGE_GENERIC 0x01
#define REPORT_USAGE_PAGE_KEYBOARD 0x07
#define REPORT_USAGE_PAGE_LEDS 0x08
#define REPORT_USAGE_PAGE_BUTTON 0x09
#define REPORT_USAGE_PAGE_CONSUMER 0x0C
#define REPORT_USAGE_PAGE_VENDOR 0xff00

#define REPORT_USAGE_CONSUMER_CONTROL 0x01

#define HID_LOCAL_ITEM_TAG_USAGE 0x00
#define HID_LOCAL_ITEM_TAG_USAGE_MIN 0x01
#define HID_LOCAL_ITEM_TAG_USAGE_MAX 0x02

#define HID_GLOBAL_ITEM_TAG_USAGE_PAGE 0x00
#define HID_GLOBAL_ITEM_TAG_LOGICAL_MINIMUM 0x01
#define HID_GLOBAL_ITEM_TAG_LOGICAL_MAXIMUM 0x02
#define HID_GLOBAL_ITEM_TAG_PHYSICAL_MINIMUM 0x03
#define HID_GLOBAL_ITEM_TAG_PHYSICAL_MAXIMUM 0x04
#define HID_GLOBAL_ITEM_TAG_REPORT_SIZE 0x07
#define HID_GLOBAL_ITEM_TAG_REPORT_ID 0x08
#define HID_GLOBAL_ITEM_TAG_REPORT_COUNT 0x09

#define HID_MAIN_ITEM_TAG_INPUT 0x08
#define HID_MAIN_ITEM_TAG_COLLECTION_START 0x0A
#define HID_MAIN_ITEM_TAG_COLLECTION_END 0x0C

#define HID_INPUT_VARIABLE 0x02

#define HID_COLLECTION_APPLICATION 0x01

#define HID_ITEM_FORMAT_SHORT 0
#define HID_ITEM_FORMAT_LONG 1

#define HID_ITEM_TAG_LONG 15

#define MAX_HID_DEVICES 8

// SB should be one less than the total number of bits
#define SIGNEX(v, sb) ((v) | (((v) & (1 << (sb))) ? ~((1 << (sb))-1) : 0))

typedef struct _EndPoint
{
	unsigned char EndpointAddr;
	unsigned short MaxPacketSize;

	unsigned char EndpointDir : 1;
	unsigned char TOG : 1;
} EndPoint, *PEndPoint;

typedef struct _HID_GLOBAL
{
	uint8_t usagePage;
	int32_t logicalMinimum;
	uint32_t logicalMaximum;
	INT8 physicalMinimum;
	INT8 physicalMaximum;
	uint8_t unitExponent;
	uint8_t unit;
	uint8_t reportID;
	uint8_t reportSize;
	uint8_t reportCount;
} HID_GLOBAL;

typedef struct _HID_LOCAL
{
	uint32_t usage;
	uint32_t usageMin;
	uint32_t usageMax;

} HID_LOCAL;

// maps a joystick control to a keyboard or mouse output

#define MAP_KEYBOARD 0
#define MAP_MOUSE 1
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

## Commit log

2022-08-15 keyboard modifiers, inhibit protocol bugfixes
    [ps2.h]
2022-08-19 schematic entry, test PCB layout
    [KMDGX-8S-BS_rC6.STEP, LQFP-48_7x7mm_P0.5mm.step, TL1250FxxxxxRCLR.stp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]
2022-08-21 update PCB
    [ps2usb.kicad_pcb, ps2usb.kicad_sch]
2022-08-29 PCB + enclosure
    [frontcase-B_Cu.gbr, frontcase-B_Mask.gbr, frontcase-B_Silkscreen.gbr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]
2022-09-01 more ground fill clearance
    [ps2usb.kicad_pcb]
2022-09-01 Schematic cleanups
    [ps2usb.kicad_pcb, ps2usb.kicad_sch]
2022-09-01 new pinout
    [ps2usb.kicad_sch]
2022-09-03 fixed some keyboard protocol bugs
    [main.c]
2022-09-05 Mouse chunky buffer
    [ps2usb.kicad_sch]
2022-09-07 switch HID devices to Boot Mode
2022-09-15 All devices operate in Report Mode
2022-09-18 Menu system, memory optimizations
    [ps2usb.kicad_sch]
2022-10-04 Serial version hardware
    [ps2usb.kicad_pcb, ps2usb.kicad_sch]
2022-10-05 work on serial version enclosure
2022-10-23 HID report descriptor memory optimizations
    [ps2usb.kicad_pcb, ps2usb.kicad_sch]
2022-10-27 serial enclosure
    [frontcase.kicad_pcb, frontcase.step, ps2usb.kicad_pcb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]
2022-10-31 Serial version board/enclosure rework
    [frontcase.kicad_pcb, frontcase.step, ps2usb.kicad_pcb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]
2022-11-03 Finished serial enclosure
    [frontcase-B_Cu.gbr, frontcase-B_Mask.gbr, frontcase-B_Silkscreen.gbr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]
2022-11-20 3.3v LED supply
    [ps2usb.kicad_pcb, ps2usb.kicad_sch]
2022-11-20 LED PWM
2022-11-26 AXP pin assignments
2023-01-08 Replace dsub9 footprint with a more common part
    [ps2usb.kicad_pcb]
2023-01-08 Serial mouse, LEDs, Boot Mode Debugging
2023-01-09 Case sensitive compilation fixes
    [ch559.h, main.c, menu.c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]
2023-01-21 Disable UART0 for HIDman-micro as well
2023-01-21 Fix some BOARD definitions
    [main.c]
2023-01-25 Use 7 data-bits UART for serial mouse
2023-01-25 Make UART word size configurable
2023-01-26 Support 3 mouse buttons
2023-01-26 Wired up DTR instead of TXD
    [ps2usb.kicad_pcb, ps2usb.kicad_sch]
2023-01-26 board outline
    [ps2usb.kicad_pcb]
2023-01-28 Better Serial Mouse Detection routine. Also optimized timer0 interrupt a bit
2023-01-28 Wired up TXD instead of DTR
    [ps2usb.kicad_pcb, ps2usb.kicad_sch]
2023-02-16 button position change
    [frontcase.kicad_pcb, frontcase.step, ps2usb.kicad_pcb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]
2023-02-19 AXP PCB tidyup
    [frontcase-B_Cu.gbr, frontcase-B_Mask.gbr, frontcase-B_Silkscreen.gbr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]
2023-02-19 reorganized hardware dir
    [c-1825027-5-h-3d.stp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]
2023-03-07 Fix race with timer interrupt 1 that also modifies PS/2 mouse clock pin 3.7
    [main.c]
2023-05-12 added axp bom
    [BOM.csv]
2023-07-25 Increase number of hub ports to 4
    Seems to be common that 2 port hubs are actually 4 port hubs.
    Needed to safe some memory, so INTERFACE are now no longer static arrays per device
    [usbhost.h]
2024-03-23 Keyboard LEDs now update
2024-04-29 Implemented support for PS/2 mouse data reporting enable / disable.
    Data reporting support does fix problem where certain PS/2 controllers will disable
    mouse port on POST if mouse is transmitting anhything while data reporting is off.
    There are also stub functions for implementing scaling / resolution etc, but not
    implemented yet.
    [mouse.c, mouse.h]
2024-05-06 Initial Intellimouse support. Detection works, 4-byte data packets works, middle mouse button works.
    Wheel does not work and intellimouse is forced.
    [main.c, mouse.c, mouse.h]
2024-05-06 Wheel scrolling almost works but not there yet... Cannot wrap my head around USB reports etc.
2024-05-06 Now intellimouse detection works properly and reports are sized accordingly (3 bytes, 4 bytes). CuteMouse driver and Win98 with IntelliMouse driver works with 3rd button and wheel, MS mouse driver wo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
    Wheel support is still hacked together as I cannot figure out how HID reports should be properly
    parsed. But it works...
2024-05-06 Attempted to add wheel to standard mouse descriptor.
2024-05-06 Support for 5 button intellimouse added.
2024-05-08 Output rate limiter (to fix menu on XT)
    [menu.c, ps2.h]
2024-05-09 Watchdog resets enable "safe mode"
    [main.c, settings.c, system.c]
2024-05-16 debug dump device reenumeration
2024-05-22 one transfer per frame
2024-05-22 crystal osc, disabled switch
2024-05-23 fewer bulk transfer initiations per frame
2024-05-28 Added crystal to PCB
    [ps2usb.csv, ps2usb.kicad_pcb, ps2usb.kicad_sch]
2024-05-28 Software for new switch pin, refactoring, latest gerbers,
    [ps2usb-B_Cu.gbr, ps2usb-B_Mask.gbr, ps2usb-B_Silkscreen.gbr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]
2024-06-08 redundant code cleanup
    [ps2usb.kicad_pcb]
2024-06-08 usb poll frequency bug
    [main.c]
2024-06-10 Interrupt fixes
2024-06-11 moved some capacitors around
    [ps2usb.kicad_pcb]
2024-06-18 Colorblind-safe LED colors
2024-07-06 HIDman PS/2 version updated from current AXP
    [frontcase-B_Cu.gbr, frontcase-B_Mask.gbr, frontcase-B_Silkscreen.gbr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]
2024-07-07 Cleaned up rogue tracks.
    [ps2usb.kicad_pcb]
2024-07-07 Clean up of labels and logo.
    [ps2usb-B_Cu.gbr, ps2usb-B_Mask.gbr, ps2usb-B_Silkscreen.gbr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]
2024-07-11 add presets, fix memory leak
    [menu.c]
2024-07-19 Create ps2usb-BOM.xlsx
    Updated BOM
    [ps2usb-BOM.xlsx]
2024-07-19 Update ps2usb-BOM.xlsx
    BOM update
    [ps2usb-BOM.xlsx]
2024-07-19 Corrected SMD sizes, updated BOM and placement.
    [frontcase.kicad_pcb, ps2usb-BOM.xlsx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]
2024-07-24 Added step file for front
    [frontcase.step]
2024-07-24 Updated recommended length of button
    8mm actuator length instead of 9.5mm. JLCPCB part number not updated due to lack of availability.
    [ps2usb-BOM.xlsx]
2024-09-02 menu fixes, lots more test data
    [main.c, menu.c, system.c]
2024-09-25 saved UNDO information for reset changes and discarded files
    [menu.c]
2024-10-17 keyboard tester
    [KEYDEFS.OBJ, KEYNAMES.OBJ, KEYTEST.OBJ]
2024-10-17 Keyboard tester work
    [KEYDEFS.OBJ, KEYTEST.OBJ]
2024-10-17 compilation fixes
    [KEYDEFS.OBJ, KEYTEST.OBJ]
2024-10-18 added weird BIOS scancodes
    [KEYDEFS.OBJ, KEYTEST.OBJ]
2024-10-18 massively optimized key tester
    [KEYDEFS.OBJ, KEYTEST.OBJ]
2024-10-19 Added lots of extra keys
    [KEYDEFS.OBJ, KEYTEST.OBJ]
2024-10-20 hilarious new name for key tester
    [KEYDEFS.OBJ, KEYNAMES.OBJ, KEYTEST.OBJ]
2024-11-05 unified debug, report mode fixes
    [menu.c, ps2.h]
2024-12-15 data generator
    [keyboard_data.csv]
2024-12-17 data generator integration
    [keyboard_data.csv]
2024-12-18 mashpipe build automation
    [MASHPIPE.CFG, keyboard_data.csv]
2024-12-19 datagen, mashpipe fixes
    [keyboard_data.csv]
2025-04-25 async menu, backslash fix
    [menu.c, processreport.c, settings.c]
2025-04-30 Mouse inhibit logic fixes
    [menu.c]
2025-05-22 Joystick analog stick fix
    [defs.h, mouse.c, processreport.c]
2025-05-22 Joypad Mouse click button fix
    [processreport.c]
2025-09-11 Add troubleshooting note for HIDman device detection
    Added troubleshooting note for HIDman connection issues.
2025-11-26 started implementing media keys
    [keyboard_data.csv]
2026-01-08 LED goes red when enumerating
2026-01-09 Hopefully fixed mouse reset issue
    [ps2.h]
2026-06-20 Allow forcing Fn keys on Logitech wireless keyboards
    Some modern Logitech wireless keyboards with Unifying receivers like the K400+
    default to using media keys on the function keys. This adds a setting to force
    those keyboards to treat them to be used as standard F1-F12 function keys.
    Only tested on the Logitech K400+. Solaar (https://github.com/pwr-Solaar/Solaar)
    used as a reference for the Logitech HID++ protocol.
